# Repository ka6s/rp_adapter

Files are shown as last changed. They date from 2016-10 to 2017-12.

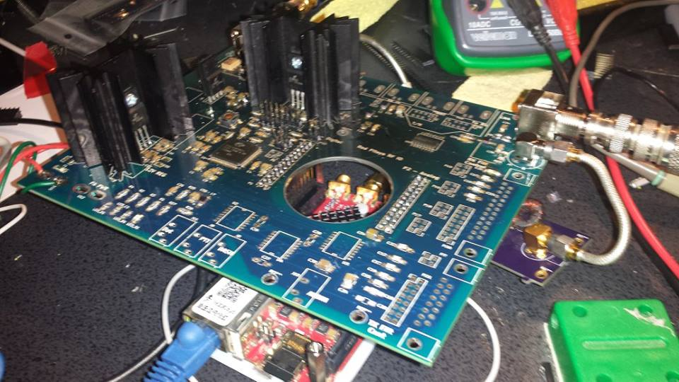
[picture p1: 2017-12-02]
DebugRev1.jpg

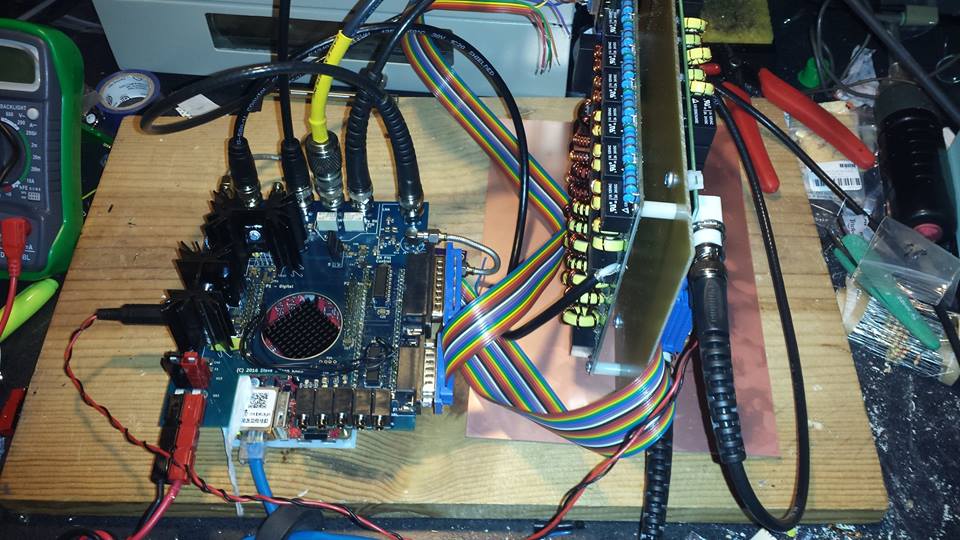
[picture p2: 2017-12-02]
rev3_with_filters.jpg

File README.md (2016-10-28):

# rp_adapter : v4

# rp_adapter

This is the layout of the 4th iteration of this board.  Currently the design in this directory is the 
transceiver consisting of a connector to the Red Pitaya, the OpenHPSDR TAPR LPU, the OpenHPSDR TAPR T/R board, 
a 1W PA taken from the OpenHPSDR Penelope board, and a simple 18db ish LNA.  

The connecitivy is built to interface to an external amplifier, the Hermes RX Filter from EB104.ru and
the 300W LPF from EB104.ru. You need to get the amp keying from the EB104.ru LPF board. 

Enjoy

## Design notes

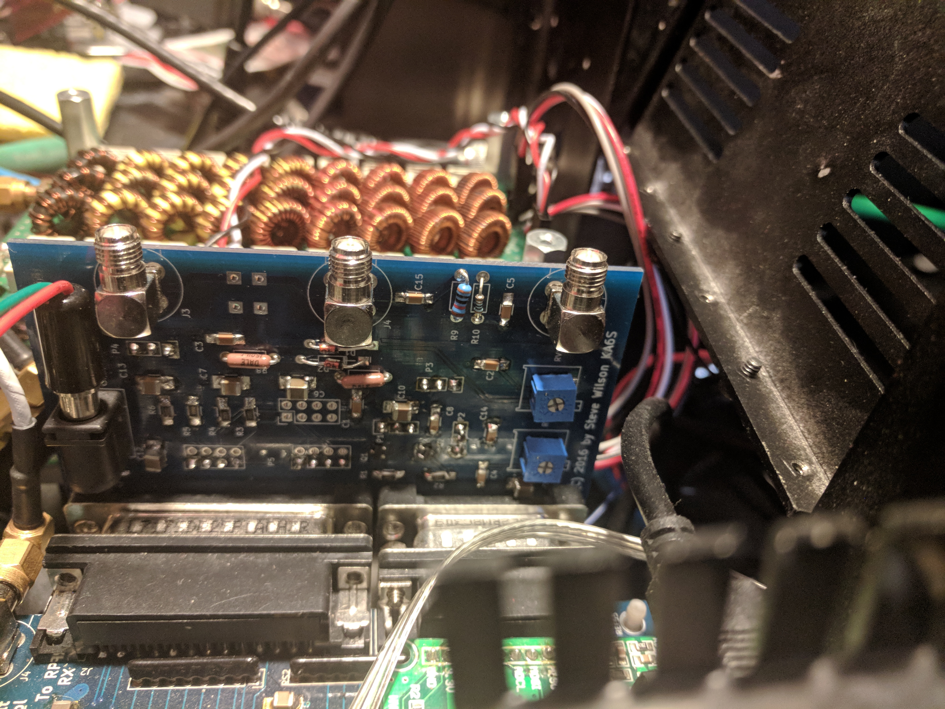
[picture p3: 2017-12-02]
swr.jpg

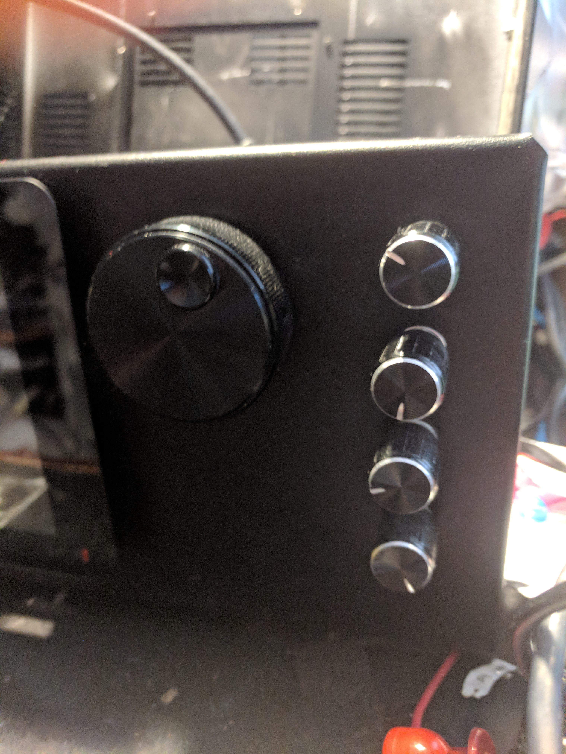
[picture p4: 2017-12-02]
knobs_front.jpg

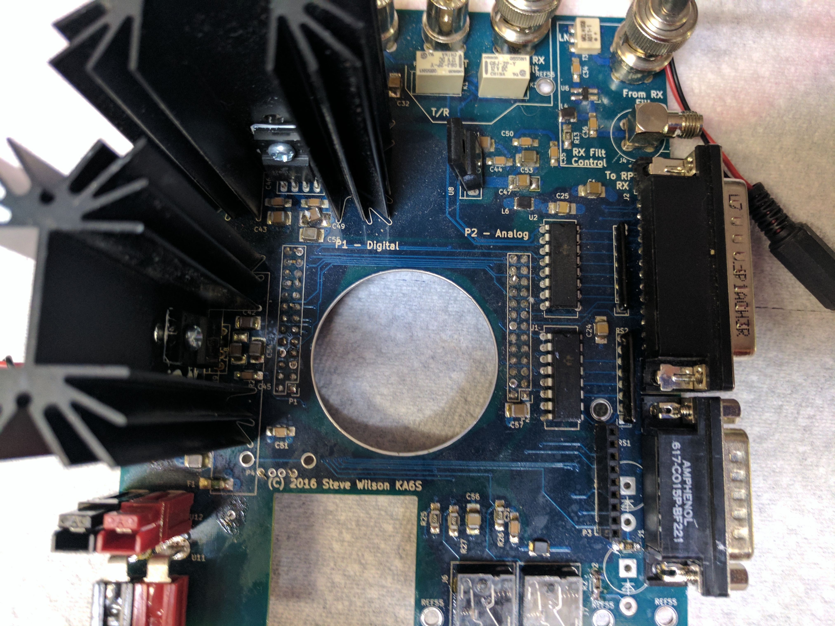
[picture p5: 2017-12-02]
ver4.jpg

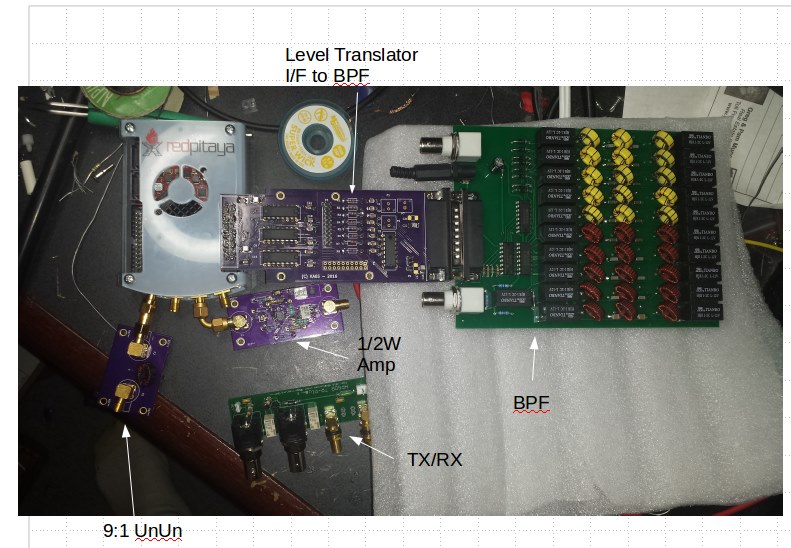
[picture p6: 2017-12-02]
Levelshifter.jpg

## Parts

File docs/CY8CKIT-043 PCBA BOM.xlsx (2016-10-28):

TITLE |  | CY8CKIT-043 PSoC 4 M-Series Prototyping Kit
PCA # |  | 121-60220-01 | REV 04
SCH # |  | 630-60252-01 | REV 04
DATE |  | 2015-06-24
Item | Qty | Reference | Value | Description | Manufacturer | Mfr Part Number | Sub Allowed | ROHS | UL Certified
1 | 1 | 600-60250-01 REV04 | - | PCB, 116.51 mm x 24.13 mm, High Tg, ENIG finish, 2 layer, Color = RED, Silk = WHITE | Cypress Semiconductor | 600-60250-01 | N/A | Yes | Yes
2 | 14 | C1,C4,C5,C6,C8,C11,C14,C18,C19,C20,C22,C29,C33,C34 | 0.1 uFd | CAP CER 0.1UF 10V 10% X5R 0402 | TDK Corporation | C1005X5R1A104K050BA | ASK | Yes | Yes
3 | 13 | C3,C15,C16,C17,C21,C23,C24,C25,C26,C27,C28,C31,C32 | 1.0 uFd | CAP CERAMIC 1.0UF 25V X5R 0603 10% | Taiyo Yuden | TMK107BJ105KA-T | ASK | Yes | Yes
4 | 1 | C9 | 18 pF | CAP CER 18PF 50V 1% NP0 0402 | Murata Electronics | GRM1555C1H180FA01D | ASK | Yes | Yes
5 | 1 | C10 | 2200 pFd | CAP CER 2200PF 50V 5% NP0 0805 | Murata | GRM2165C1H222JA01D | ASK | Yes | Yes
6 | 1 | C12 | 36 pF | CAP CER 36PF 50V 5% NP0 0402 | Murata Electronics | GRM1555C1H360JA01D | ASK | Yes | Yes
7 | 1 | C13 | 10000 pFd | CAP CER 10000PF 50V 5% NP0 0805 | Murata | GRM2195C1H103JA01D | ASK | Yes | Yes
8 | 1 | D1 | MBR0520L | DIODE SCHOTTKY 0.5A 20V SOD-123 | Fairchild Semiconductor | MBR0520L | ASK | Yes | Yes
9 | 1 | F1 | PTC Resettable Fuse | FUSE, PTC Resettable, 0.50A, 16V, 1210, SMD | Bel Fuse Inc | 0ZCH0050FF2G | ASK | Yes | Yes
10 | 1 | LED1 | User LED BLUE | LED, BLUE, CLEAR, 0805, SMD | Lite-On Inc | LTST-C170TBKT | ASK | Yes | Yes
11 | 1 | LED2 | Power LED Amber | LED 595NM AMB DIFF 0805 SMD | Avago Technologies | HSMA-C170 | ASK | Yes | Yes
12 | 1 | LED3 | Status LED Green | LED GREEN CLEAR 0805 SMD | Chicago Miniature | CMD17-21VGC/TR8 | ASK | Yes | Yes
13 | 3 | L1,L2,L3 | 330 OHM @ 100MHz | FILTER CHIP 330 OHM 1.5A 0603 | Murata Electronics | BLM18SG331TN1D | ASK | Yes | Yes
14 | 2 | R2,R3 | 15K | RES SMD 15K OHM 5% 1/10W 0402 | Panasonic - ECG | ERJ-2GEJ153X | ASK | Yes | Yes
15 | 2 | R4,R5 | 22E | RES SMD 22 OHM 1% 1/10W 0402 | Panasonic - ECG | ERJ-2RKF22R0X | ASK | Yes | Yes
16 | 2 | R6,R8 | 2.2K | RES 2.2K OHM 1/10W 5% 0603 SMD | Panasonic - ECG | ERJ-3GEYJ222V | ASK | Yes | Yes
17 | 2 | R7,R22 | ZERO | RES 0.0 OHM 1/8W 0805 SMD | Panasonic-ECG | ERJ-6GEY0R00V | ASK | Yes | Yes
18 | 1 | R9 | 560 ohm | RES 560 OHM 1/10W 5% 0603 SMD | Panasonic - ECG | ERJ-3GEYJ561V | ASK | Yes | Yes
19 | 2 | R10,R12 | 30K | RES SMD 30K OHM 5% 1/10W 0402 | Panasonic - ECG | ERJ-2GEJ303X | ASK | Yes | Yes
20 | 12 | R11,R13,R14,R16,R17,R18,R20,R21,R24,R26,R27,R28 | ZERO | RES 0.0 OHM 1/8W 0603 SMD | Panasonic-ECG | ERJ-3GEY0R00V | ASK | Yes | Yes
21 | 1 | R15 | 560 ohm | RES 560 OHM 1/8W 5% 0805 SMD | Panasonic - ECG | ERJ-6GEYJ561V | ASK | Yes | Yes
22 | 1 | R19 | 820 ohm | RES 820 OHM 1/8W 5% 0603 SMD | Panasonic - ECG | ERJ-3GEYJ821V | ASK | Yes | Yes
23 | 2 | SW1,SW3 | SW PUSHBUTTON | SWITCH TACTILE SPST-NO 0.05A 32V | C&K Components | KMR221GLFS | ASK | Yes | Yes
24 | 1 | U1 | PSoC 5LP | 68QFN PSoC 5LP chip for USB debug channel and USB-Serial interface | Cypress Semiconductor | CY8C5868LTI-LP039 | ASK | Yes | Yes
25 | 1 | U2 | PSoC 4200M | 68TQFP PSoC 4M | Cypress Semiconductor | CY8C4247AZI-M485 | ASK | Yes | Yes
26 | 1 | U3 | DUAL PMOS | MOSFET 2P-CH 20V 430MA SOT-563 | ON Semiconductor | NTZD3152PT1G | ASK | Yes | Yes
Label
27 | 1 | N/A | N/A | LBL, PCA Label, Vendor Code, Datecode, Serial Number 121-60220-01 Rev 04 (YYWWVVXXXXX) | Cypress Semiconductor |  | ASK | Yes | Yes
No load components
28 | 2 | C2,C30 | 0.1 uFd | CAP CER 0.1UF 10V 10% X5R 0402 | TDK Corporation | C1005X5R1A104K050BA | ASK | Yes | Yes
29 | 1 | C7 | 1.0 uFd | CAP CERAMIC 1.0UF 25V X5R 0603 10% | Taiyo Yuden | TMK107BJ105KA-T | ASK | Yes | Yes
30 | 1 | J4 | HDR 1x2 | CONN HEADR BRKWAY .100 02POS STR | TE Connectivity | 9-146280-0-02 | ASK | Yes | Yes
31 | 1 | J5 | 50MIL KEYED SMD | CONN HEADER 10 PIN 50MIL KEYED SMD | Samtec | FTSH-105-01-L-DV-K | ASK | Yes | Yes
32 | 1 | R1 | 4.7K | RES SMD 4.7K OHM 5% 1/10W 0402 | Panasonic - ECG | ERJ-2GEJ472X | ASK | Yes | Yes
33 | 1 | R25 | ZERO | RES 0.0 OHM 1/8W 0805 SMD | Panasonic - ECG | ERJ-6GEY0R00V | ASK | Yes | Yes
34 | 1 | R23 | 4.7K | RES 4.7K OHM 1/10W 5% 0603 SMD | Panasonic - ECG | ERJ-3GEYJ472V | ASK | Yes | Yes
35 | 1 | SW2 | SW PUSHBUTTON | SWITCH TACTILE SPST-NO 0.05A 32V | C&K Components | KMR221GLFS | ASK | Yes | Yes
36 | 1 | SW4 | DPDT SW | SWITCH SLIDE DPDT 200MA 12V | Copal Electronics | CL-SB-22B-02T | ASK | Yes | Yes
37 | 1 | TP5 | BLACK | TEST POINT 43 HOLE 65 PLATED BLACK | Keystone Electronics | 5001 | ASK | Yes | Yes
38 | 4 | TP1,TP2,TP3,TP4 | RED | TEST POINT 43 HOLE 65 PLATED RED | Keystone Electronics | 5000 | ASK | Yes | Yes
39 | 1 | U4 | EZ-BLE | EZ-BLE PRoC BLE Module, 10 mm X 10 mm X 1.8 mm | Cypress Semiconductor | CYBLE-022001-00 | ASK | Yes | Yes

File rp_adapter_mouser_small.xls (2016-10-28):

Mouser Part number | Manufacturer | Mfg Part Number | Description | Location | Quantity | Price 1 | Cost/Unit/10 | Location | Price 1 | Min\Mult Order Qty | Quoted Part Number
81-GRM422X105K50L (http://www.mouser.com/ProductDetail/Murata-Electronics/GRM32RR71H105KA01L/) | Murata | GRM32RR71H105KA01L (http://www.mouser.com/ProductDetail/Murata-Electronics/GRM32RR71H105KA01L/) | 1uF | C53,C55,C57,C54,C40 | 7 | 0.32 | 0.17 |  | $0.17 | 1\1 | 81-GRM422X105K50L
81-GRM422R106K16L (http://www.mouser.com/ProductDetail/Murata-Electronics/GRM32DR61C106KA01L/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) | Murata | GRM32DR61C106KA01L (http://www.mouser.com/ProductDetail/Murata-Electronics/GRM32DR61C106KA01L/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) | 10uF | C30,C2,C47,C49,C48,C41,C37,C42,C43 | 10 | 0.32 | 0.185 |  | $0.255 | 1\1 | 81-GRM422R106K16L
80-C1206C104K5R (http://www.mouser.com/ProductDetail/Kemet/C1206C104K5RACTU/) | Kemet | C1206C104K5RACTU (http://www.mouser.com/ProductDetail/Kemet/C1206C104K5RACTU/) | 0.1uF | C44,C50,C35,C36,C34,C33,C39,C38,C45,C51,C46,C52,C31 | 15 | 0.1 | 0.042 |  | $0.042 | 1\1 | 80-C1206C104K5R
80-C1210C107M4PACTU (http://www.mouser.com/ProductDetail/Kemet/C1210C107M4PACTU/) | Kemet | C1210C107M4PACTU (http://www.mouser.com/ProductDetail/Kemet/C1210C107M4PACTU/) | 100uF | C55,C54,C53,C40,C57,C1 | 7 | 2.46 | 0.836 |  | $2.46 | 1\1 | 80-C1210C107M4PACTU
490-PJ-002BH | Cui | PJ-002BH | BARREL_JACK | CON1 | 1 | 1.16 | 1.25 |  | $1.16 | 1\1 | 490-PJ-002BH
576-0437005.WR (http://www.mouser.com/ProductDetail/Littelfuse/0437005WR/) | Littelfuse (http://www.mouser.com/littelfuse) | 0437005.WR (http://www.mouser.com/ProductDetail/Littelfuse/0437005WR/) | FUSE | F1 | 1 | 0.92 | 0.688 |  | $0.92 | 1\1 | 576-0437005.WR
532-529801B25G | Aavid Thermalloy | 529801B02500G | HEATSINK | HS3,HS2 | 2 | 1.47 | 1.39 |  | $1.47 | 1\1 | 532-529801B25G
710-618015231221 (http://www.mouser.com/ProductDetail/Wurth-Electronics/618015231221/?qs=sGAEpiMZZMt93J8DTi5DC553G%252bzlR8Bc) | Wurth | 618015231221 (http://www.mouser.com/ProductDetail/Wurth-Electronics/618015231221/?qs=sGAEpiMZZMt93J8DTi5DC553G%252bzlR8Bc) | DB15 | J1 | 1 | 3.21 | 3.06 |  | $3.21 | 1\1 | 710-618015231221
523-L717SDB25P1ACH3R | Amphenol | L717SDB25P1ACH3R (http://www.mouser.com/ProductDetail/Amphenol-Commercial-Products/L717SDB25P1ACH3R/) | DB25 | J2 | 1 | 2.38 | 2.28 |  | $2.38 | 1\1 | 523-L717SDB25P1ACH3R
712-CONSMA002 (http://www.mouser.com/ProductDetail/Linx-Technologies/CONSMA002/?qs=K5ta8V%252bWhtYroTuiMsq2AA%3D%3D) | Linx Tech | CONSMA002 (http://www.mouser.com/ProductDetail/Linx-Technologies/CONSMA002/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) | SMA | J4,J3,J5 | 3 | 3.31 | 3.03 |  | $3.31 | 1\1 | 712-CONSMA002
490-SJ1-3533N (http://www.mouser.com/ProductDetail/CUI/SJ1-3533N/) | Cui | SJ1-3533N | JACK_2P | J11,J10,J9,J8,J6 | 5 | 1.6 | 1.24 |  | $1.60 | 1\1 | 490-SJ1-3533N
653-G6J-2P-Y-DC12 (http://www.mouser.com/ProductDetail/Omron-Electronics/G6J-2P-Y-DC12/) | Omron | G6J-2P-Y-DC12 | RELAY_RF | K2,K1 | 2 | 4.29 | 4.03 |  | $4.29 | 1\1 | 653-G6J-2P-Y-DC12
81-NFZ32BW621HN10L | Murata | NFZ32BW621HN10L | FB | L5,L4,L6,L3,L7 | 6 | 0.41 | 0.269 |  | $0.269 | 1\1 | 81-NFZ32BW621HN10L
563-BC-32678 | Bud Industries | BC-32678 | CONN_02X13 | P2,P1 | 2 | 2 | 1.8 |  | $2.00 | 1\1 | 563-BC-32678
652-CR1206FX-75R0ELF (http://www.mouser.com/ProductDetail/Bourns/CR1206-FX-75R0ELF/) | Bourns | CR1206-FX-75R0ELF (http://www.mouser.com/ProductDetail/Bourns/CR1206-FX-75R0ELF/) | 75 | R13 | 5 | 0.1 | 0.042 |  | $0.10 | 1\1 | 652-CR1206FX-75R0ELF
667-ERJ-8RQF5R1V (http://www.mouser.com/ProductDetail/Panasonic/ERJ-8RQF5R1V/) | Panasonic | ERJ-8RQF5R1V (http://www.mouser.com/ProductDetail/Panasonic/ERJ-8RQF5R1V/) | 5R1 | R22,R21 | 5 | 0.56 | 0.22 |  | $0.56 | 1\1 | 667-ERJ-8RQF5R1V
71-CP00102R200JE663 | Vishay | CP00102R200JE663 | 2R2 | R24,R23 | 2 | 0.67 | 0.495 |  | $4.29 | 1\1 | 653-G6J-2P-Y-DC12
667-ERJ-8GEYJ472V (http://www.mouser.com/ProductDetail/Panasonic/ERJ-8GEYJ472V/) | Panasonic | ERJ-8GEYJ472V (http://www.mouser.com/ProductDetail/Panasonic/ERJ-8GEYJ472V/) | 4.7K | R27,R25,R26 | 5 | 0.1 |  |  | $0.022 | 1\1 | 667-ERJ-8GEYJ472V
512-KA278R12CTU (http://www.mouser.com/ProductDetail/Fairchild-Semiconductor/KA278R12CTU/) | Fairchild | KA278R12CTU (http://www.mouser.com/ProductDetail/Fairchild-Semiconductor/KA278R12CTU/) | KA278R12 | U10 | 1 | 0.99 | 0.848 |  | $0.99 | 1\1 | 512-KA278R12CTU
879-1336G1 (http://www.mouser.com/ProductDetail/Anderson-Power-Products/1336G1/?qs=sGAEpiMZZMuP%2FQeRSdvksJ%2FdnJShAKpx) | Anderson Power Products (http://www.mouser.com/Anderson-Power-Products/) | 1336G1 (http://www.mouser.com/ProductDetail/Anderson-Power-Products/1336G1/?qs=sGAEpiMZZMuP%2FQeRSdvksJ%2FdnJShAKpx) | PwrPole | U11 | 2 | 0.54 |  |  | $0.54 | 1\1 | 879-1336G1
879-1327G6 (http://www.mouser.com/ProductDetail/Anderson-Power-Products/1327G6/?qs=sGAEpiMZZMuP%2FQeRSdvksFwvD3ebCz4Y) | Anderson Power Products (http://www.mouser.com/Anderson-Power-Products/) | 1327G6 | 1327G6 (http://www.mouser.com/ProductDetail/Anderson-Power-Products/1327G6/?qs=sGAEpiMZZMuP%2FQeRSdvksFwvD3ebCz4Y) | U12,U11 | 2 |  |  |  | $0.48 | 1\1 | 879-1327G6
879-1327 (http://www.mouser.com/ProductDetail/Anderson-Power-Products/1327/?qs=sGAEpiMZZMuP%2FQeRSdvksHAvir4742Xo) | Anderson Power Products (http://www.mouser.com/Anderson-Power-Products/) | 1327 | PwrPole Shroud Red | U12,U11 | 2 |  |  |  | $0.50 | 1\1 | 879-1327
879-1335G1 (http://www.mouser.com/ProductDetail/Anderson-Power-Products/1335G1/?qs=sGAEpiMZZMuP%2FQeRSdvksBiQHnjEfqU3) | Anderson Power Products (http://www.mouser.com/Anderson-Power-Products/) | 1335G1 (http://www.mouser.com/ProductDetail/Anderson-Power-Products/1335G1/?qs=sGAEpiMZZMuP%2FQeRSdvksBiQHnjEfqU3) | Powe Pole Vert | U12 | 2 |  |  |  |  | 1\1 | 879-1335G1
700-MAX2611EUS+T (http://www.mouser.com/ProductDetail/Maxim-Integrated/MAX2611EUS+T/?qs=GxOUx7aO6nzhsdyrBwYTYA%3D%3D) | Maxim | MAX2611EUS+T | MAX2611 | U6 | 1 | 1.78 | 1.68 |  | $1.78 | 1\1 | 700-MAX2611EUS+T
595-OPA2674ID (http://www.mouser.com/ProductDetail/Texas-Instruments/OPA2674ID/?qs=7nS3%252bbEUL6ta%252bQbwv%2FJuYg%3D%3D) | TI | OPA2674ID (http://www.mouser.com/ProductDetail/Texas-Instruments/OPA2674ID/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) | OPA26741C | U7 | 1 | 4.14 | 3.72 |  | $4.14 | 1\1 | 595-OPA2674ID
512-KA278R05CTU | Fairchild | KA278R05CTU | KA278R05 | U8,U9 | 2 | 0.98 | 0.836 |  | $0.98 | 1\1 | 512-KA278R05CTU
571-5-1634506-1 | TE Connectivity (http://www.mouser.com/TE-Connectivity/) | 5-1634506-1 | BNC_VERTICAL | P8,P10,P14,P9,P15 | 5 | 1.36
511-ULN2001A | STMicro | ULN2001A | ULN2004A | U1,U2 | 2 | 0.47
279-CBT50J100R (http://www.mouser.com/ProductDetail/TE-Connectivity-Neohm/CBT50J100R/) | TE Connectivity | CBT25J100R (http://www.mouser.com/ProductDetail/TE-Connectivity-Neohm/CBT25J100R/) | 100 | R15,R16 | 2
603-MFR-25FRF521K (http://www.mouser.com/ProductDetail/Yageo/MFR-25FRF52-1K/) | Yageo | MFR-25FRF52-1K (http://www.mouser.com/ProductDetail/Yageo/MFR-25FRF52-1K/) | 1K | R18,R17,R19,R20 | 4
 |  |  | CONN_01X29 | P3,P4 | 2

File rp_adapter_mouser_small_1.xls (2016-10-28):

Mouser Part number | Manufacturer | Mfg Part Number | Description | Location | Quantity | Price 1 | Cost/Unit/10 | Location | Price 1 | Min\Mult Order Qty | Quoted Part Number
81-GRM422X105K50L (http://www.mouser.com/ProductDetail/Murata-Electronics/GRM32RR71H105KA01L/) | Murata | GRM32RR71H105KA01L (http://www.mouser.com/ProductDetail/Murata-Electronics/GRM32RR71H105KA01L/) | 1uF | C56,C32,C25,C24,C9,C7,C5,C3,C2,C1 | 20 | 0.32 | 0.17 |  | $0.17 | 1\1 | 81-GRM422X105K50L
80-C1206C101K5R (http://www.mouser.com/ProductDetail/Kemet/C1206C101K5RACTU/) | Kemet | C1206C101K5RACTU (http://www.mouser.com/ProductDetail/Kemet/C1206C101K5RACTU/) | 100pF | C23,C22,C21,C20,C18,C17,C16,C15,C14,C13,C12,C19 | 15 | 0.1 | 0.042 |  | $0.185 | 1\1 | 80-C1206C101K5R
81-GRM422R106K16L (http://www.mouser.com/ProductDetail/Murata-Electronics/GRM32DR61C106KA01L/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) | Murata | GRM32DR61C106KA01L (http://www.mouser.com/ProductDetail/Murata-Electronics/GRM32DR61C106KA01L/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) | 10uF | C49,C48,C47,C43,C42,C41,C37,C30 | 10 | 0.32 | 0.185 |  | $0.255 | 1\1 | 81-GRM422R106K16L
80-C1206C104K5R (http://www.mouser.com/ProductDetail/Kemet/C1206C104K5RACTU/) | Kemet | C1206C104K5RACTU (http://www.mouser.com/ProductDetail/Kemet/C1206C104K5RACTU/) | 0.1uF | C52,C51,C50,C46,C45,C44,C39,C38,C36,C35,C34,C33,C31,C29,C28,C27,C26,C11,C10,C8,C6,C4 | 25 | 0.1 | 0.042 |  | $0.042 | 1\1 | 80-C1206C104K5R
80-C1210C107M4PACTU (http://www.mouser.com/ProductDetail/Kemet/C1210C107M4PACTU/) | Kemet | C1210C107M4PACTU (http://www.mouser.com/ProductDetail/Kemet/C1210C107M4PACTU/) | 100uF | C55,C54,C53,C40,C57 (1210) | 8 | 2.46 | 0.836 |  | $2.46 | 1\1 | 80-C1210C107M4PACTU
490-PJ-002BH | Cui | PJ-002BH | BARREL_JACK | CON1 | 1 | 1.16 | 1.25 |  | $1.16 | 1\1 | 490-PJ-002BH
576-0437005.WR (http://www.mouser.com/ProductDetail/Littelfuse/0437005WR/) | Littelfuse (http://www.mouser.com/littelfuse) | 0437005.WR (http://www.mouser.com/ProductDetail/Littelfuse/0437005WR/) | FUSE | F1 | 1 | 0.92 | 0.688 |  | $0.92 | 1\1 | 576-0437005.WR
532-529801B25G | Aavid Thermalloy | 529801B02500G | HEATSINK | HS3,HS2 | 2 | 1.47 | 1.39 |  | $1.47 | 1\1 | 532-529801B25G
710-618015231221 (http://www.mouser.com/ProductDetail/Wurth-Electronics/618015231221/?qs=sGAEpiMZZMt93J8DTi5DC553G%252bzlR8Bc) | Wurth | 618015231221 (http://www.mouser.com/ProductDetail/Wurth-Electronics/618015231221/?qs=sGAEpiMZZMt93J8DTi5DC553G%252bzlR8Bc) | DB15 | J1 | 1 | 3.21 | 3.06 |  | $3.21 | 1\1 | 710-618015231221
523-L717SDB25P1ACH3R | Amphenol | L717SDB25P1ACH3R (http://www.mouser.com/ProductDetail/Amphenol-Commercial-Products/L717SDB25P1ACH3R/) | DB25 | J2 | 1 | 2.38 | 2.28 |  | $2.38 | 1\1 | 523-L717SDB25P1ACH3R
712-CONSMA002 (http://www.mouser.com/ProductDetail/Linx-Technologies/CONSMA002/?qs=K5ta8V%252bWhtYroTuiMsq2AA%3D%3D) | Linx Tech | CONSMA002 (http://www.mouser.com/ProductDetail/Linx-Technologies/CONSMA002/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) | SMA | J5,J4,J3 | 3 | 3.31 | 3.03 |  | $3.31 | 1\1 | 712-CONSMA002
490-SJ1-3533N (http://www.mouser.com/ProductDetail/CUI/SJ1-3533N/) | Cui | SJ1-3533N | JACK_2P | J11,J10,J9,J8,J6 | 5 | 1.6 | 1.24 |  | $1.60 | 1\1 | 490-SJ1-3533N
653-G6J-2P-Y-DC12 (http://www.mouser.com/ProductDetail/Omron-Electronics/G6J-2P-Y-DC12/) | Omron | G6J-2P-Y-DC12 | RELAY_RF | K2,K1 | 2 | 4.29 | 4.03 |  | $4.29 | 1\1 | 653-G6J-2P-Y-DC12
81-LQH31MNR47K03L (http://www.mouser.com/ProductDetail/Murata-Electronics/LQH31MNR47K03L/) | Murata | LQH31MNR47K03L (http://www.mouser.com/ProductDetail/Murata-Electronics/LQH31MNR47K03L/) | 0.47uH | L2,L1 | 2 | 0.44 | 0.335 |  | $0.44 | 1\1 | 81-LQM31PNR47MC0L
81-NFZ32BW621HN10L | Murata | NFZ32BW621HN10L | FB | L6,L5,L4,L3,L7 | 6 | 0.41 | 0.269 |  | $0.269 | 1\1 | 81-NFZ32BW621HN10L
645-598-8270-107F (http://www.mouser.com/ProductDetail/Dialight/598-8270-107F/) | Dialight | 598-8270-107F (http://www.mouser.com/ProductDetail/Dialight/598-8270-107F/) | LED | LED_D1,LED_C1,LED_B1,LED_A1 | 4 | 0.46 |  |  | $0.46 | 1\1 | 645-598-8270-107F
563-BC-32678 | Bud Industries | BC-32678 | CONN_02X13 | P2,P1 | 2 | 2 | 1.8 |  | $2.00 | 1\1 | 563-BC-32678
571-5227677-1 | TE Connectivity | 5227677-1 | BNC | P15,P14,P11,P10,P9,P8 | 6 | 3.3 | 3.17 |  | $3.30 | 1\1 | 571-5227677-1
652-CR1206FX-75R0ELF (http://www.mouser.com/ProductDetail/Bourns/CR1206-FX-75R0ELF/) | Bourns | CR1206-FX-75R0ELF (http://www.mouser.com/ProductDetail/Bourns/CR1206-FX-75R0ELF/) | 75 | R13 | 5 | 0.1 | 0.042 |  | $0.10 | 1\1 | 652-CR1206FX-75R0ELF
667-ERJ-8GEYJ101V (http://www.mouser.com/ProductDetail/Panasonic/ERJ-8GEYJ101V/) | Bourns | ERJ-8GEYJ101V (http://www.mouser.com/ProductDetail/Panasonic/ERJ-8GEYJ101V/) | 100 | R16,R15 | 5 | 0.1 | 0.022 |  | $0.10 | 1\1 | 667-ERJ-8GEYJ101V
652-CR1206-JW-102ELF (http://www.mouser.com/ProductDetail/Bourns/CR1206-JW-102ELF/) | Bourns | CR1206-JW-102ELF (http://www.mouser.com/ProductDetail/Bourns/CR1206-JW-102ELF/) | 1K | R20,R19,R18,R17 | 5 | 0.1 | 0.039 |  | $0.038 | 1\1 | 652-CR1206-JW-102ELF
667-ERJ-8RQF5R1V (http://www.mouser.com/ProductDetail/Panasonic/ERJ-8RQF5R1V/) | Panasonic | ERJ-8RQF5R1V (http://www.mouser.com/ProductDetail/Panasonic/ERJ-8RQF5R1V/) | 5R1 | R22,R21 | 5 | 0.56 | 0.22 |  | $0.56 | 1\1 | 667-ERJ-8RQF5R1V
71-CP00102R200JE663 | Vishay | CP00102R200JE663 | 2R2 | R24,R23 | 2 | 0.67 | 0.495 |  | $4.29 | 1\1 | 653-G6J-2P-Y-DC12
667-ERJ-8GEYJ472V (http://www.mouser.com/ProductDetail/Panasonic/ERJ-8GEYJ472V/) | Panasonic | ERJ-8GEYJ472V (http://www.mouser.com/ProductDetail/Panasonic/ERJ-8GEYJ472V/) | 4.7K | R26,R25,R5,R4,R3,R2,R1,R27 | 10 | 0.1 |  |  | $0.022 | 1\1 | 667-ERJ-8GEYJ472V
791-WR12X000PTL | Waisun | WR12X000 PTL | 0 | R12,R11,R10,R9,R8,R7,R6 | 10 | 0.11 |  |  | $0.11 | 1\1 | 791-WR12X000PTL
653-B3S-1000 (http://www.mouser.com/ProductDetail/Omron-Electronics/B3S-1000/) | Omron | B3S-1000 (http://www.mouser.com/ProductDetail/Omron-Electronics/B3S-1000/) | SW_PUSH | SW1 | 1 | 0.61 |  |  | $0.61 | 1\1 | 653-B3S-1000
727-CY8C4247AXI-M485 (http://www.mouser.com/ProductDetail/Cypress-Semiconductor/CY8C4247AXI-M485/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) | Cypress | CY8C4247AXI-M485 | CY8C4247AXIM | U1 | 1 | 6.37 | 5.51 |  | $6.37 | 1\1 | 727-CY8C4247AXI-M485
512-KA278R12CTU (http://www.mouser.com/ProductDetail/Fairchild-Semiconductor/KA278R12CTU/) | Fairchild | KA278R12CTU (http://www.mouser.com/ProductDetail/Fairchild-Semiconductor/KA278R12CTU/) | KA278R12 | U10 | 1 | 0.99 | 0.848 |  | $0.99 | 1\1 | 512-KA278R12CTU
879-1336G1 (http://www.mouser.com/ProductDetail/Anderson-Power-Products/1336G1/?qs=sGAEpiMZZMuP%2FQeRSdvksJ%2FdnJShAKpx) | Anderson Power Products (http://www.mouser.com/Anderson-Power-Products/) | 1336G1 (http://www.mouser.com/ProductDetail/Anderson-Power-Products/1336G1/?qs=sGAEpiMZZMuP%2FQeRSdvksJ%2FdnJShAKpx) | PwrPole | U11 | 2 | 0.54 |  |  | $0.54 | 1\1 | 879-1336G1
879-1327G6 (http://www.mouser.com/ProductDetail/Anderson-Power-Products/1327G6/?qs=sGAEpiMZZMuP%2FQeRSdvksFwvD3ebCz4Y) | Anderson Power Products (http://www.mouser.com/Anderson-Power-Products/) | 1327G6 | 1327G6 (http://www.mouser.com/ProductDetail/Anderson-Power-Products/1327G6/?qs=sGAEpiMZZMuP%2FQeRSdvksFwvD3ebCz4Y) | U12,U11 | 2 |  |  |  | $0.48 | 1\1 | 879-1327G6
879-1327 (http://www.mouser.com/ProductDetail/Anderson-Power-Products/1327/?qs=sGAEpiMZZMuP%2FQeRSdvksHAvir4742Xo) | Anderson Power Products (http://www.mouser.com/Anderson-Power-Products/) | 1327 | PwrPole Shroud Red | U12,U11 | 2 |  |  |  | $0.50 | 1\1 | 879-1327
879-1335G1 (http://www.mouser.com/ProductDetail/Anderson-Power-Products/1335G1/?qs=sGAEpiMZZMuP%2FQeRSdvksBiQHnjEfqU3) | Anderson Power Products (http://www.mouser.com/Anderson-Power-Products/) | 1335G1 (http://www.mouser.com/ProductDetail/Anderson-Power-Products/1335G1/?qs=sGAEpiMZZMuP%2FQeRSdvksBiQHnjEfqU3) | Powe Pole Vert | U12 | 2 |  |  |  |  | 1\1 | 879-1335G1
595-CD4504BPWR (http://www.mouser.com/ProductDetail/Texas-Instruments/CD4504BPWR/?qs=LSR%252bNeaw%2FwDSi1l0SFbsAw%3D%3D) | TI | CD4504BPWR (http://www.mouser.com/ProductDetail/Texas-Instruments/CD4504BPWR/?qs=sGAEpiMZZMt7FrWooXVB1wQa44IR8MfB) | 4504 | U2,U3,U4 | 3 | 0.44 | 0.368 |  | $0.44 | 1\1 | 595-CD4504BPWR
595-ULN2003ADR | ULN2003ADR (http://www.mouser.com/ProductDetail/Texas-Instruments/ULN2003ADR/?qs=D5pVkbrsqqI8WxXD0eSvDA%3D%3D) | ULN2003ADR (http://www.mouser.com/ProductDetail/Texas-Instruments/ULN2003ADR/?qs=sGAEpiMZZMtYFXwiBRPs04XApsoE6l9l) | ULN2003 | U5 | 1 | 0.52 | 0.433 |  | $0.52 | 1\1 | 595-ULN2003ADR
700-MAX2611EUS+T (http://www.mouser.com/ProductDetail/Maxim-Integrated/MAX2611EUS+T/?qs=GxOUx7aO6nzhsdyrBwYTYA%3D%3D) | Maxim | MAX2611EUS+T | MAX2611 | U6 | 1 | 1.78 | 1.68 |  | $1.78 | 1\1 | 700-MAX2611EUS+T
595-OPA2674ID (http://www.mouser.com/ProductDetail/Texas-Instruments/OPA2674ID/?qs=7nS3%252bbEUL6ta%252bQbwv%2FJuYg%3D%3D) | TI | OPA2674ID (http://www.mouser.com/ProductDetail/Texas-Instruments/OPA2674ID/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) | OPA26741C | U7 | 1 | 4.14 | 3.72 |  | $4.14 | 1\1 | 595-OPA2674ID
512-KA278R05CTU | Fairchild | KA278R05CTU | KA278R05 | U9,U8 | 2 | 0.98 | 0.836 |  | $0.98 | 1\1 | 512-KA278R05CTU

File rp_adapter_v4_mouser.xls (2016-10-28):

Id | Mouser Part number | Designation | Designator | Package | Quantity | Designation | Supplier and ref
1 | 652-CR1206FX-75R0ELF (http://www.mouser.com/ProductDetail/Bourns/CR1206-FX-75R0ELF/) | 75 | R13 | R_1206_HandSoldering | 1 | 75
2 | 279-CBT50J100R (http://www.mouser.com/ProductDetail/TE-Connectivity-Neohm/CBT50J100R/) | 100 | R15,R16 | Resistor_Horizontal_RM7mm | 4 | 100
3 | 80-C1206C104K5R (http://www.mouser.com/ProductDetail/Kemet/C1206C104K5RACTU/) | 0.1uF | C51,C44,C50,C35,C36,C34,C33,C39,C38,C45,C46,C52,C31 | C_1206_HandSoldering | 20 | 0.1uF
4 | 80-C1210C107M4PACTU (http://www.mouser.com/ProductDetail/Kemet/C1210C107M4PACTU/) | 100uF | C1, C53,C55,C57,C54,C40,C11 | SMD-1210_Pol | 10 | 100uF
6 | 81-GRM422R106K16L (http://www.mouser.com/ProductDetail/Murata-Electronics/GRM32DR61C106KA01L/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) | 10uF | C41,C37,C42,C43,C47,C49,C48 | SMD-1210_Pol | 10 | 10uF
8 | 603-MFR-25FRF521K (http://www.mouser.com/ProductDetail/Yageo/MFR-25FRF52-1K/) | 1K | R18,R17,R19,R20 | Resistor_Horizontal_RM7mm | 10 | 1K
9 | 755-ESR18EZPJ102 (http://www.mouser.com/ProductDetail/ROHM-Semiconductor/ESR18EZPJ102/?qs=sGAEpiMZZMuuBt6TL7D%2F6AtTj0am7JFA) | 1K | R1,R2 | R_1206_HandSoldering | 5 | 1K
11 | 81-GRM422X105K50L (http://www.mouser.com/ProductDetail/Murata-Electronics/GRM32RR71H105KA01L/) | 1uF | C56,C32,C24,C25 | C_1210_HandSoldering | 6 | 1uF
12 | 71-CP00102R200JE663 | 2R2 | R23,R24 | RES_10W | 2 | 2R2
13 | 667-ERJ-8GEYJ472V (http://www.mouser.com/ProductDetail/Panasonic/ERJ-8GEYJ472V/) | 4.7K | R27,R25,R26 | R_1206_HandSoldering | 5 | 4.7K
14 | 660-MF1/4DCT52R4R99F (http://www.mouser.com/ProductDetail/KOA-Speer/MF1-4DCT52R4R99F/) | 4R99 | R21,R22 | Resistor_Horizontal_RM7mm | 5 | 4R99
17 | 490-PJ-002BH | BARREL_JACK | CON1 | BARREL_JACK | 1 | BARREL_JACK
18 | 571-5-1634506-1 | BNC | P8,P10,P14,P9,P15 | BNC_VERTICAL | 5 | BNC
21 | 563-BC-32678 | CONN_02X13 | P2,P1 | Pin_Header_Straight_2x13 | 2 | CONN_02X13
22 | 710-618015231221 (http://www.mouser.com/ProductDetail/Wurth-Electronics/618015231221/?qs=sGAEpiMZZMt93J8DTi5DC553G%252bzlR8Bc) | DB15 | J1 | DB15FC | 1 | DB15
23 | 523-L717SDB25P1ACH3R | DB25 | J2 | DB25FC | 1 | DB25
24 | 81-NFZ32BW621HN10L | FB | L3,L4,L5,L6,L7 | FB | 7 | FB
25 | 576-0437005.WR (http://www.mouser.com/ProductDetail/Littelfuse/0437005WR/) | FUSE | F1 | Fuse_SMD1206_HandSoldering | 2 | FUSE
26 | 588-FA-T220-64E | HEATSINK | HS3,HS2 | Heatsink_Fischer_SK129-STS_42x25mm_2xDrill2.5mm | 2 | HEATSINK
27 | 490-SJ1-3513 (http://www.mouser.com/ProductDetail/CUI/SJ1-3513/?qs=sGAEpiMZZMs8jstQXqv0yXq059P3rkIHcE6LecbulTY%3D) | JACK_3P | J6,J7 | JACK_3P | 3 | JACK_3P
28 | 512-KA278R05CTU | KA278R05 | U8,U9 | TO-220_4pin_vertical | 2 | KA278R05
29 | 512-KA278R12CTU (http://www.mouser.com/ProductDetail/Fairchild-Semiconductor/KA278R12CTU/) | KA278R12 | U10 | TO-220_4pin_vertical | 1 | KA278R12
30 | 700-MAX2611EUS+T (http://www.mouser.com/ProductDetail/Maxim-Integrated/MAX2611EUS+T/?qs=GxOUx7aO6nzhsdyrBwYTYA%3D%3D) | MAX2611 | U6 | SOT-143_Handsoldering | 2 | MAX2611
31 | 595-OPA2674ID (http://www.mouser.com/ProductDetail/Texas-Instruments/OPA2674ID/?qs=7nS3%252bbEUL6ta%252bQbwv%2FJuYg%3D%3D) | OPA26741C | U7 | SOIC-8-N | 1 | OPA26741C
32 | 879-1335G1 (http://www.mouser.com/ProductDetail/Anderson-Power-Products/1335G1/?qs=sGAEpiMZZMuP%2FQeRSdvksBiQHnjEfqU3) | PwrPole | U11,U12 | Power Pole vert | 2 | PwrPole
 | 879-1336G1 (http://www.mouser.com/ProductDetail/Anderson-Power-Products/1336G1/?qs=sGAEpiMZZMuP%2FQeRSdvksJ%2FdnJShAKpx) | PwrPole |  | RA_POWER_POLE | 2
 | 879-1327 (http://www.mouser.com/ProductDetail/Anderson-Power-Products/1327/?qs=sGAEpiMZZMuP%2FQeRSdvksHAvir4742Xo) | PwrPole |  | Power Poll shroud | 4
33 | 653-G6J-2P-Y-DC12 (http://www.mouser.com/ProductDetail/Omron-Electronics/G6J-2P-Y-DC12/) | RELAY_RF | K1,K2 | RF_RELAY | 2 | RELAY_RF
34 | 858-L081S102LF (https://www.mouser.com/Search/ProductDetail.aspx) | RSIP7 | RS1,RS2 | Pin_Header_Straight_1x08 | 2 | RSIP7
35 | 712-CONSMA002 (http://www.mouser.com/ProductDetail/Linx-Technologies/CONSMA002/?qs=K5ta8V%252bWhtYroTuiMsq2AA%3D%3D) | SMA | J4,J3,J5 | SMA_F_RA | 3 | SMA
37 | 595-ULN2003AN (https://www.mouser.com/Search/ProductDetail.aspx) | ULN2003A | U1,U2 | DIP-16_W7.62mm | 2 | ULN2004A
38 | 595-ULN2003AN (https://www.mouser.com/Search/ProductDetail.aspx) | USB_A | P4 | USBA_VERT_STVW | 1 | USB_A
39 | 863-1N5913BRLG (http://www.mouser.com/ProductDetail/ON-Semiconductor/1N5913BRLG/) | ZENER | D1,D2 | Diode_P600_Vertical_AnodeUp | 2 | ZENER

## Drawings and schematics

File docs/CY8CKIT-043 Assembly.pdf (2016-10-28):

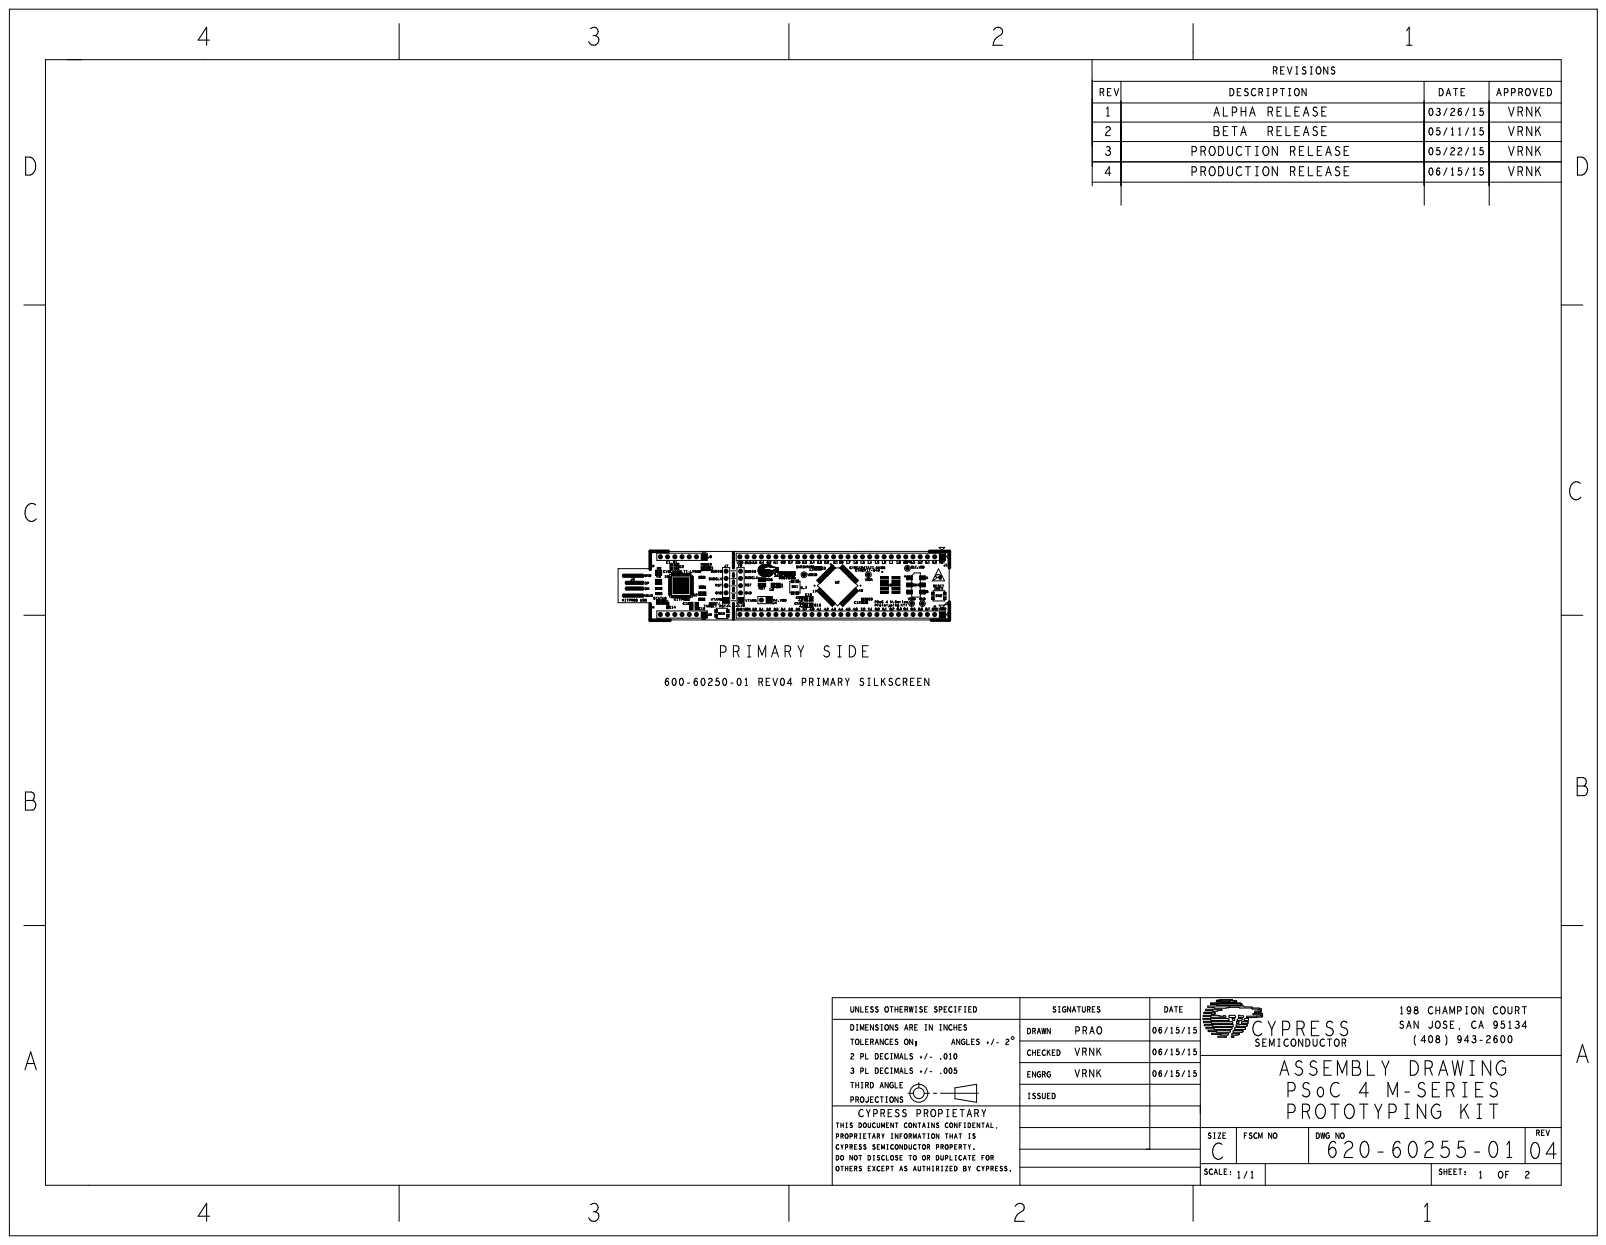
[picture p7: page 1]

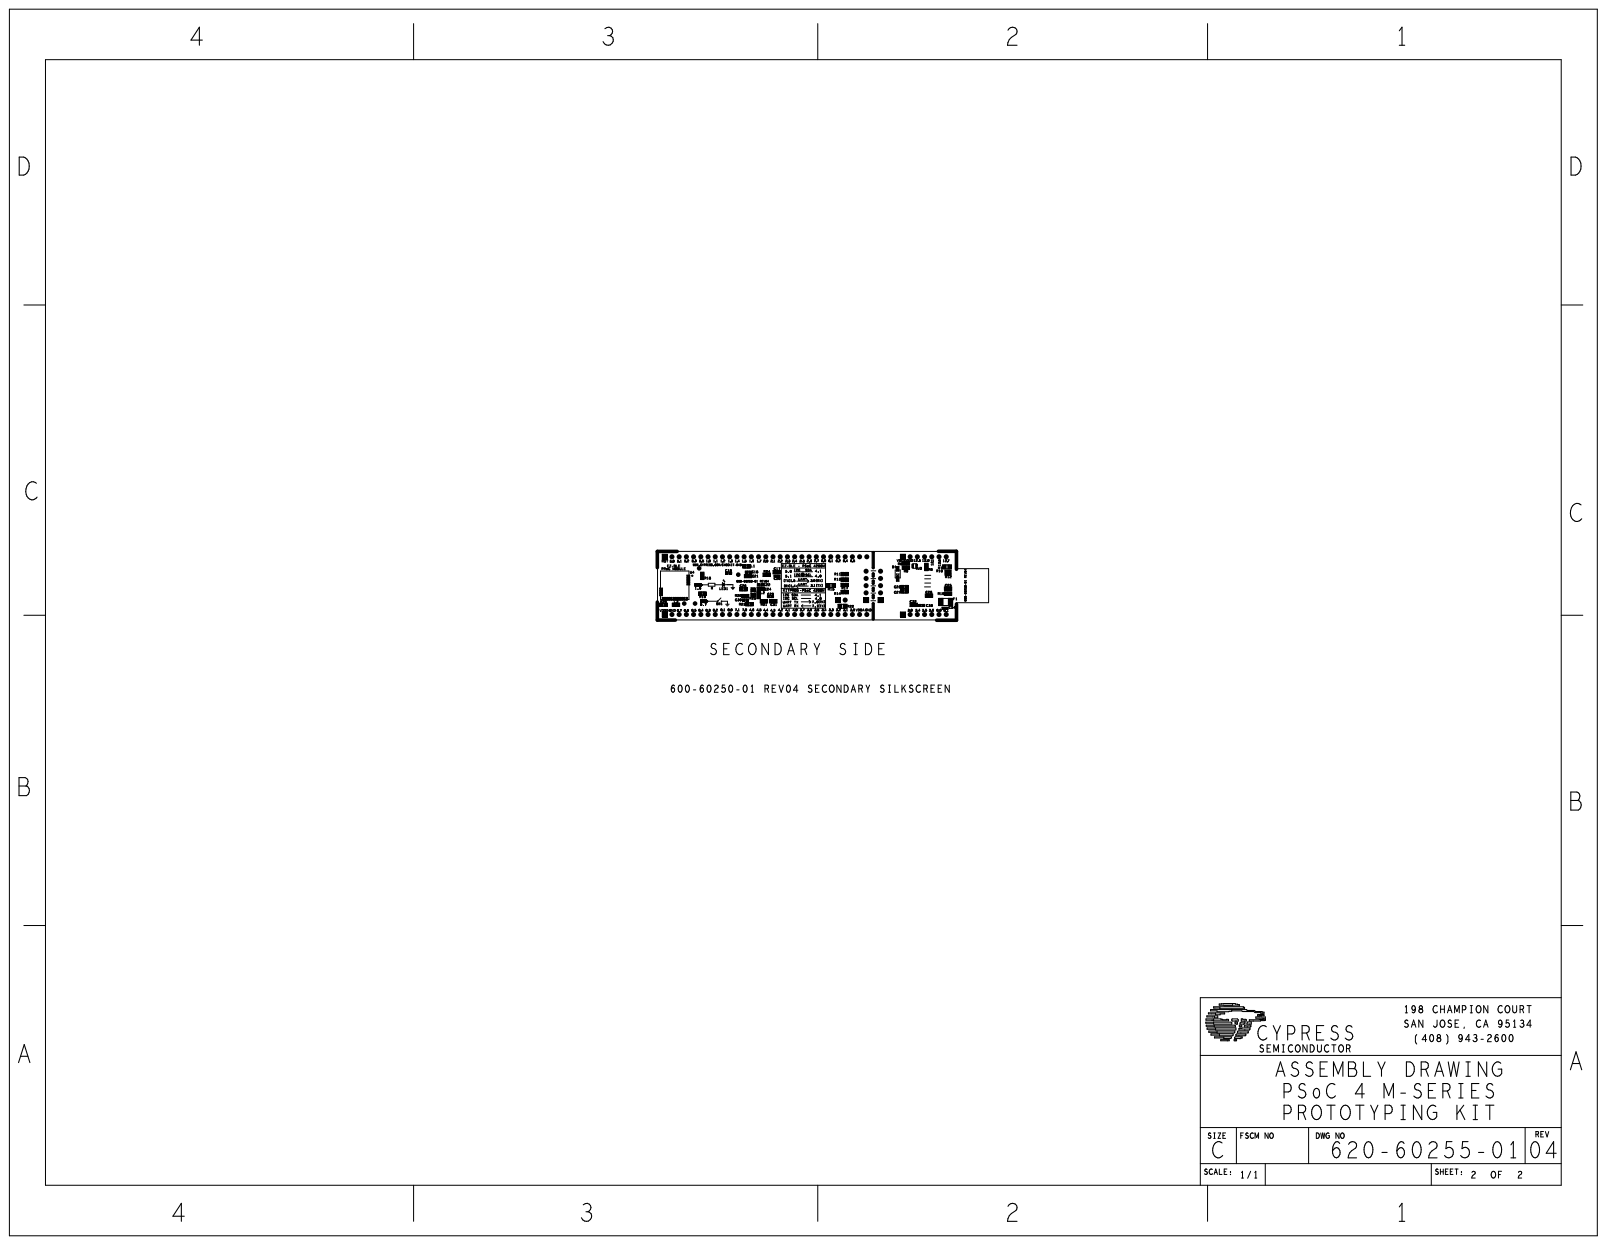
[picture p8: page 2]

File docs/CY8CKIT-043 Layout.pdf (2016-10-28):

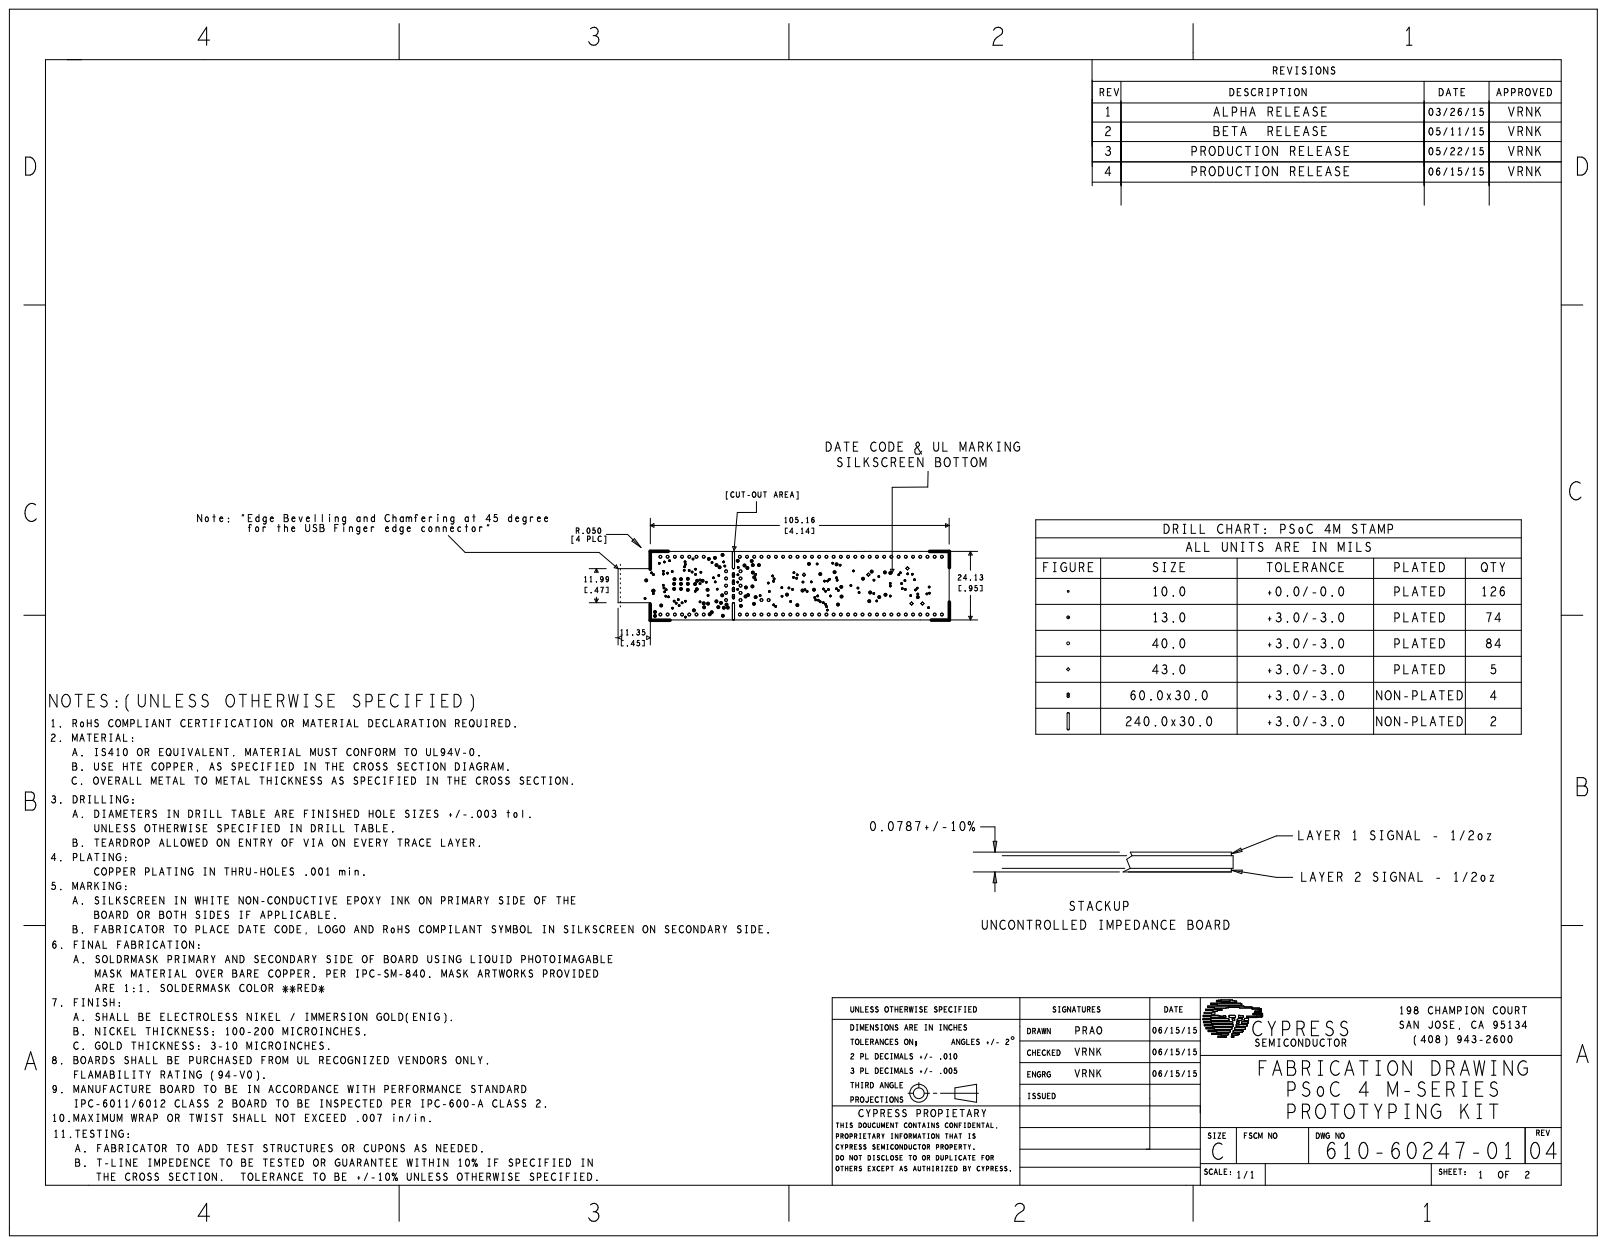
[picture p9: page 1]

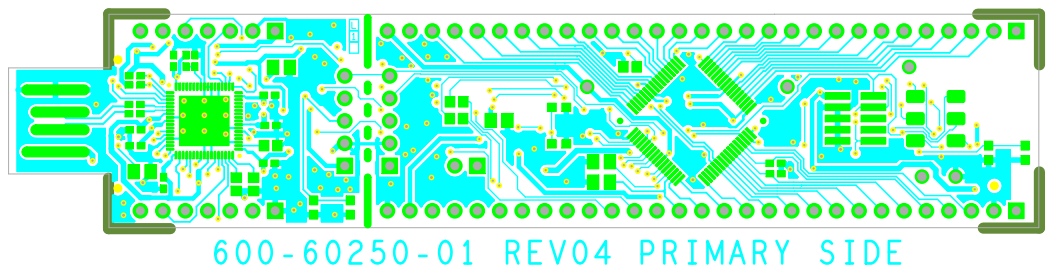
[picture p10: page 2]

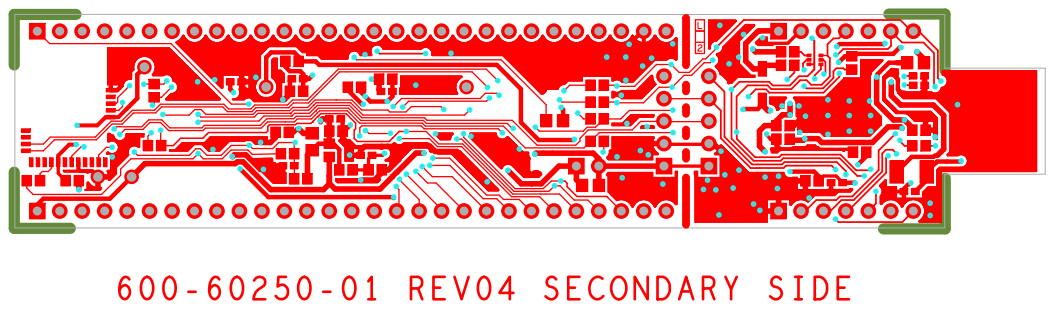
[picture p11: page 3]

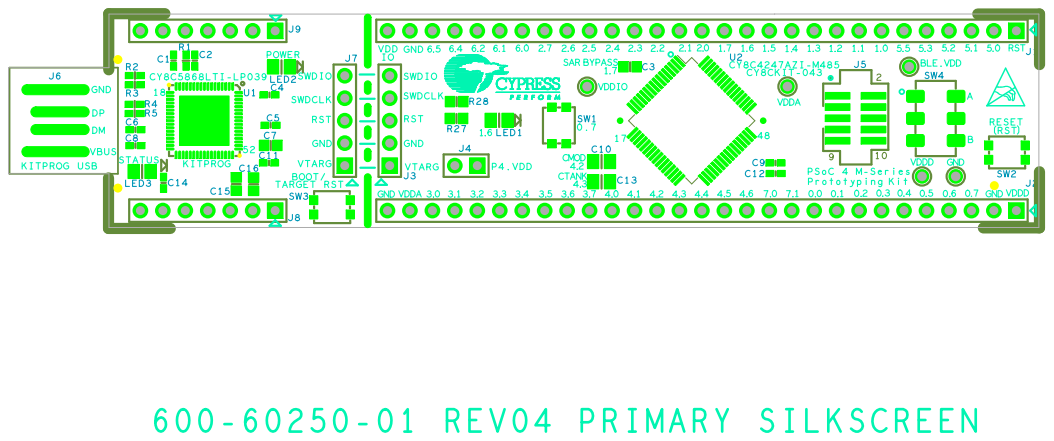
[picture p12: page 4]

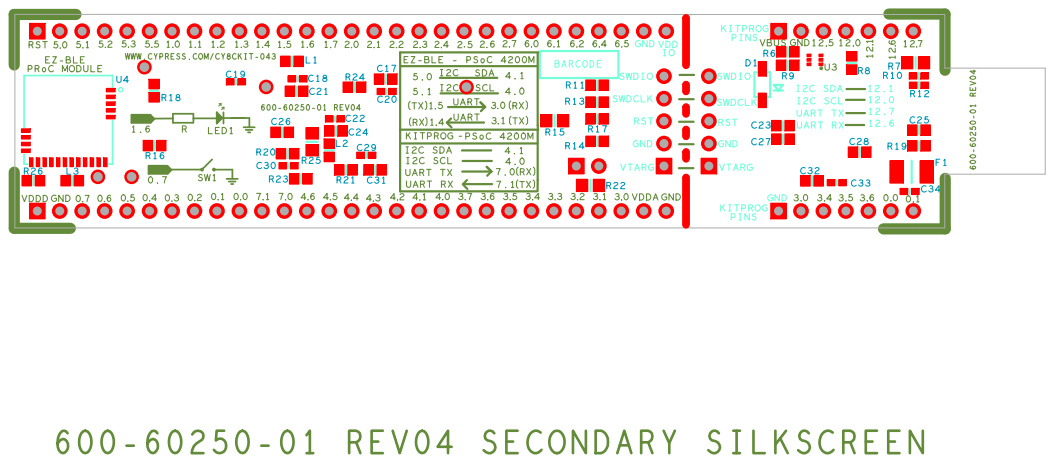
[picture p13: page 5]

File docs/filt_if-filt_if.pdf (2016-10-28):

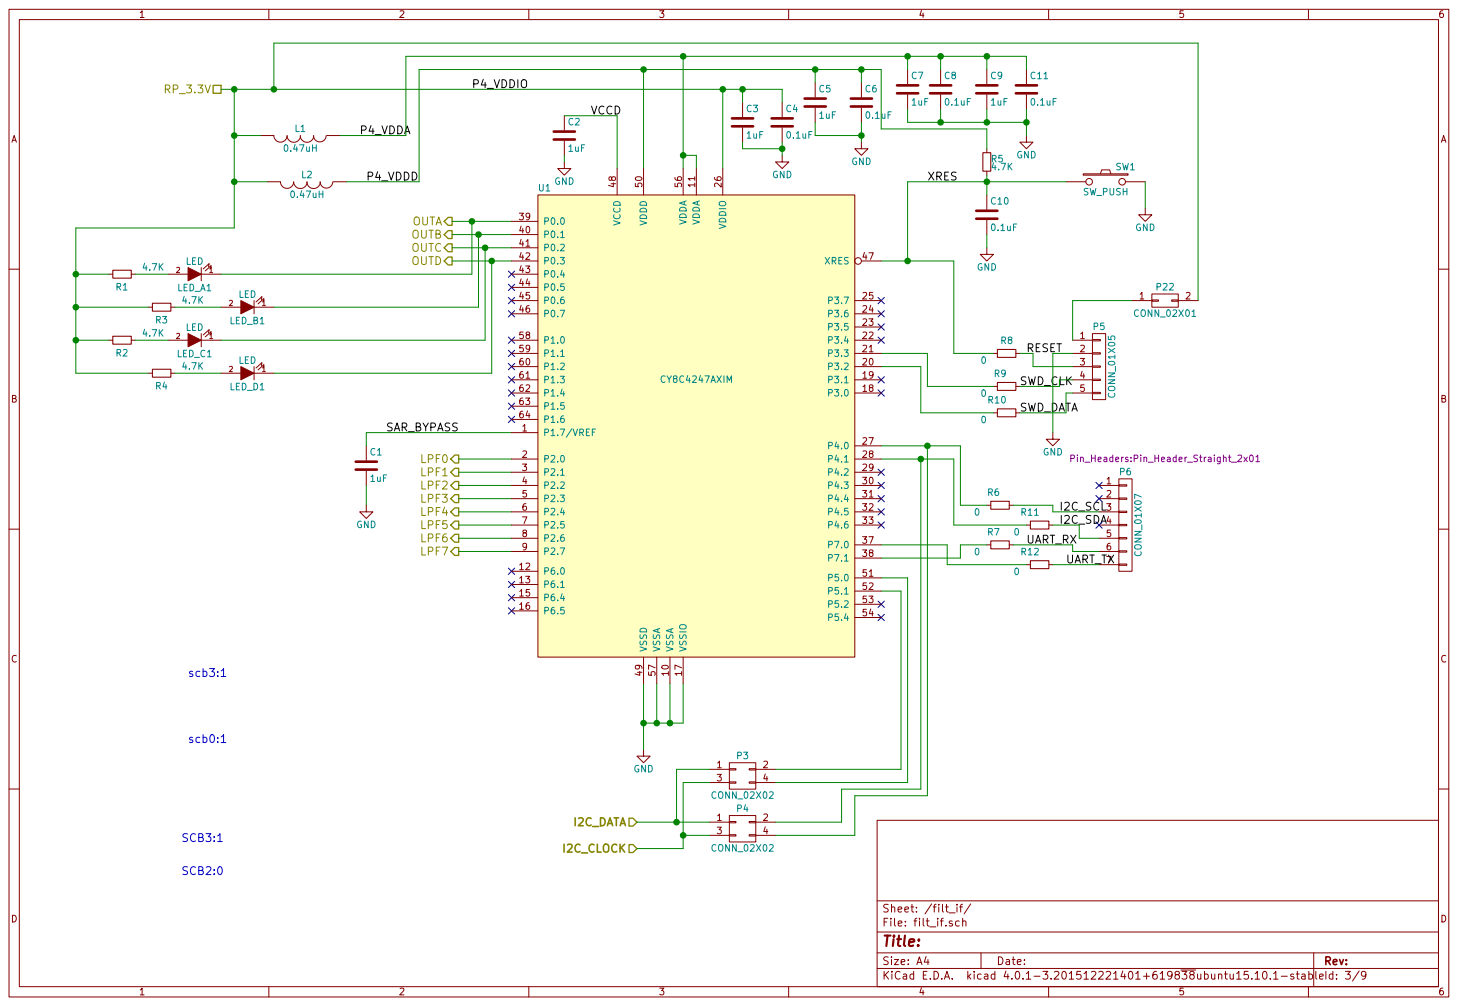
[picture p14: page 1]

VCCD | C3

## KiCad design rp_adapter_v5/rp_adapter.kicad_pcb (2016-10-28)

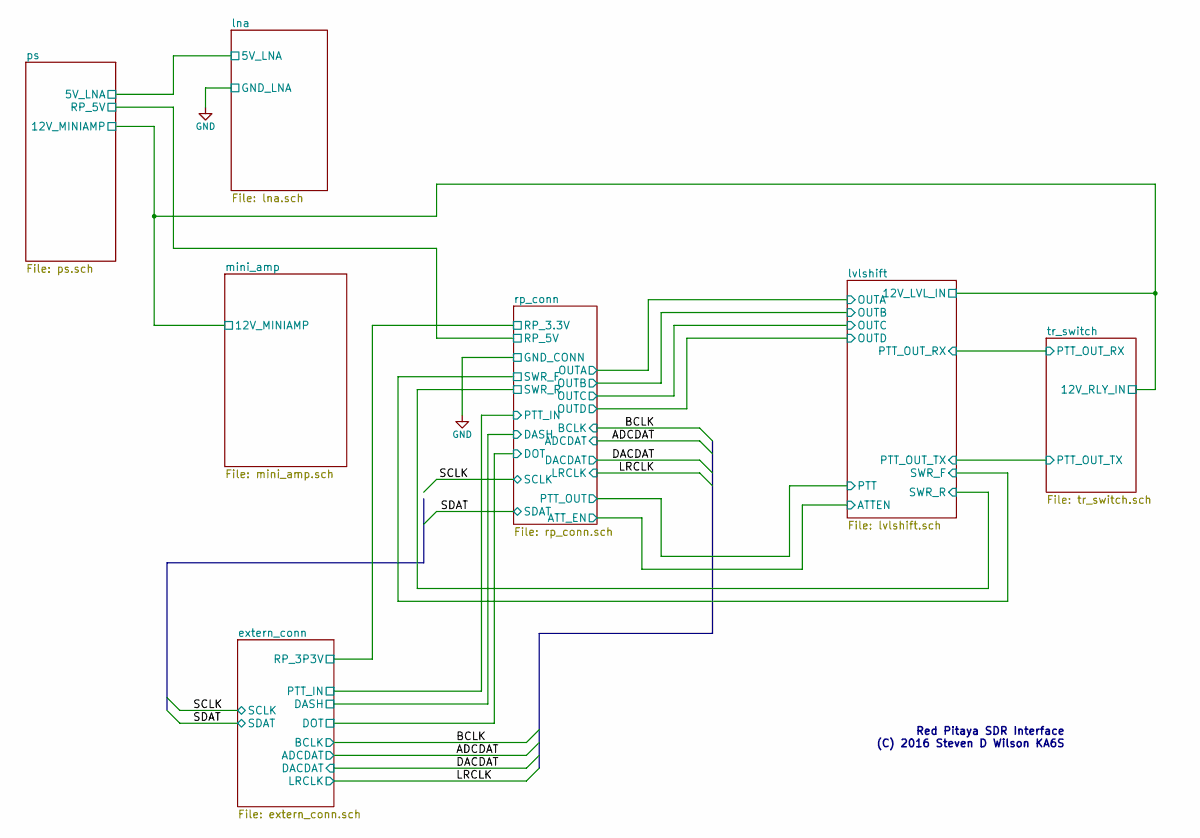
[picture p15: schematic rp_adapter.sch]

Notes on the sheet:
Red Pitaya SDR Interface (C) 2016 Steven D Wilson KA6S

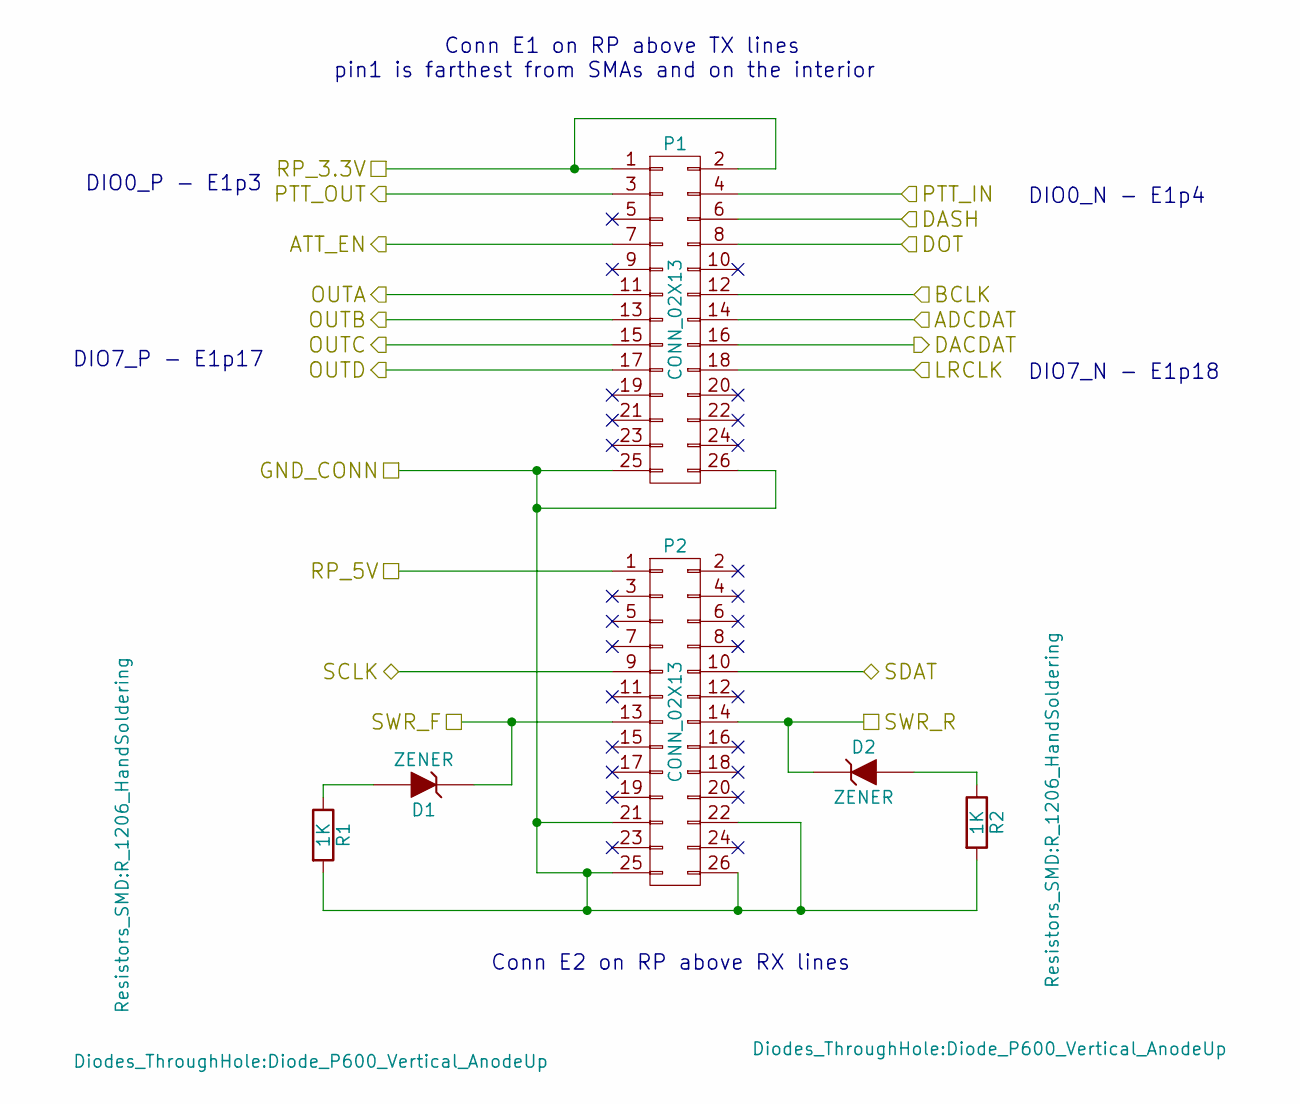
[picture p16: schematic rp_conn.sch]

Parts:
D1, D2: ZENER; Diode_P600_Vertical_AnodeUp
P1, P2: CONN_02X13; Pin_Header_Straight_2x13
R1, R2: 1K; R_1206_HandSoldering

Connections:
/extern_conn/ADCDAT: P1.14; also elsewhere on the board
/extern_conn/BCLK: P1.12; also elsewhere on the board
/extern_conn/DACDAT: P1.16; also elsewhere on the board
/extern_conn/DASH: P1.6; also elsewhere on the board
/extern_conn/DOT: P1.8; also elsewhere on the board
/extern_conn/LRCLK: P1.18; also elsewhere on the board
/extern_conn/PTT_IN: P1.4; also elsewhere on the board
/extern_conn/SCLK: P2.9; also elsewhere on the board
/extern_conn/SDAT: P2.10; also elsewhere on the board
/lvlshift/ATTEN: P1.7; also elsewhere on the board
/lvlshift/OUTA: P1.11; also elsewhere on the board
/lvlshift/OUTB: P1.13; also elsewhere on the board
/lvlshift/OUTC: P1.15; also elsewhere on the board
/lvlshift/OUTD: P1.17; also elsewhere on the board
/lvlshift/PTT: P1.3; also elsewhere on the board
/ps/RP_5V: P2.1; also elsewhere on the board
/rp_conn/RP_3.3V: P1.1, P1.2; also elsewhere on the board
/rp_conn/SWR_F: D1.1 (K), P2.13; also elsewhere on the board
/rp_conn/SWR_R: D2.1 (K), P2.14; also elsewhere on the board
GND: P1.25, P1.26, P2.21, P2.22, P2.25, P2.26, R1.2, R2.2; also elsewhere on the board
unnamed: D1.2 (A), R1.1
unnamed: D2.2 (A), R2.1

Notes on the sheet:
Conn E1 on RP above TX lines
Conn E2 on RP above RX lines
pin1 is farthest from SMAs and on the interior
DIO0_P - E1p3
DIO7_P - E1p17
DIO0_N - E1p4
DIO7_N - E1p18

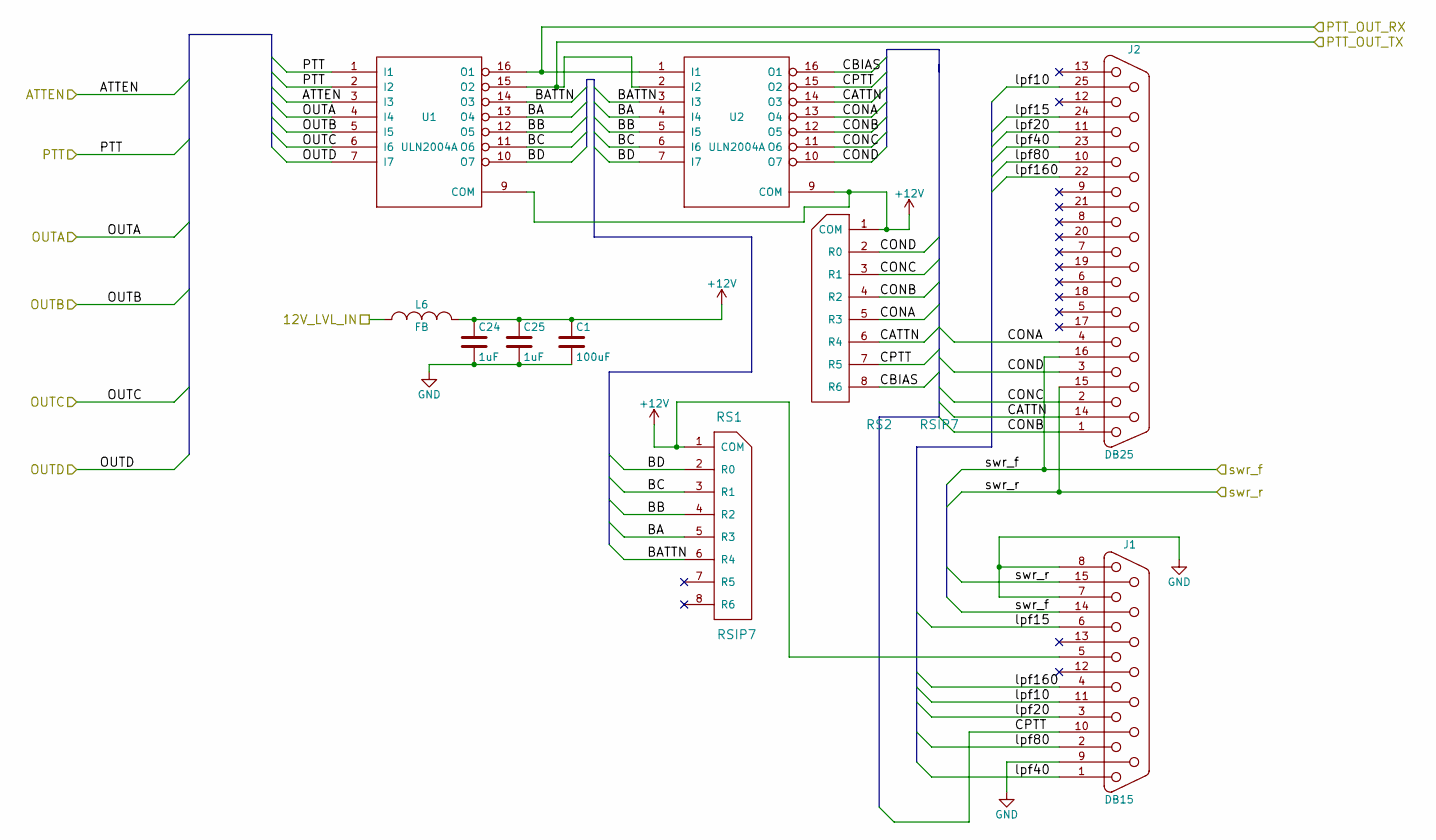
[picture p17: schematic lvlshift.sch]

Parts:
C1: 100uF; C_1210_HandSoldering
C24, C25: 1uF; C_1210_HandSoldering
J1: DB15; DB15FC
J2: DB25; DB25FC
L6: FB
RS1, RS2: RSIP7; Pin_Header_Straight_1x08
U1, U2: ULN2004A; DIP-16_W7.62mm

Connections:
+12V: C1.1, C24.1, C25.1, J1.5, L6.2, RS1.1 (COM), RS2.1 (COM), U1.9 (COM), U2.9 (COM)
/lvlshift/12V_LVL_IN: L6.1; also elsewhere on the board
/lvlshift/ATTEN: U1.3 (I3); also elsewhere on the board
/lvlshift/BA: RS1.5 (R3), U1.13 (O4), U2.4 (I4)
/lvlshift/BATTN: RS1.6 (R4), U1.14 (O3), U2.3 (I3)
/lvlshift/BB: RS1.4 (R2), U1.12 (O5), U2.5 (I5)
/lvlshift/BC: RS1.3 (R1), U1.11 (O6), U2.6 (I6)
/lvlshift/BD: RS1.2 (R0), U1.10 (O7), U2.7 (I7)
/lvlshift/CATTN: J2.14, RS2.6 (R4), U2.14 (O3)
/lvlshift/CBIAS: RS2.8 (R6), U2.16 (O1)
/lvlshift/CONA: J2.4, RS2.5 (R3), U2.13 (O4)
/lvlshift/CONB: J2.1, RS2.4 (R2), U2.12 (O5)
/lvlshift/CONC: J2.2, RS2.3 (R1), U2.11 (O6)
/lvlshift/COND: J2.3, RS2.2 (R0), U2.10 (O7)
/lvlshift/CPTT: J1.10, RS2.7 (R5), U2.15 (O2)
/lvlshift/OUTA: U1.4 (I4); also elsewhere on the board
/lvlshift/OUTB: U1.5 (I5); also elsewhere on the board
/lvlshift/OUTC: U1.6 (I6); also elsewhere on the board
/lvlshift/OUTD: U1.7 (I7); also elsewhere on the board
/lvlshift/PTT: U1.1 (I1), U1.2 (I2); also elsewhere on the board
/lvlshift/PTT_OUT_RX: U1.16 (O1), U2.1 (I1); also elsewhere on the board
/lvlshift/PTT_OUT_TX: U1.15 (O2), U2.2 (I2); also elsewhere on the board
/lvlshift/lpf10: J1.11 (P111), J2.25
/lvlshift/lpf15: J1.6, J2.24
/lvlshift/lpf20: J1.3, J2.11
/lvlshift/lpf40: J1.1, J2.23
/lvlshift/lpf80: J1.2, J2.10
/lvlshift/lpf160: J1.4, J2.22
/rp_conn/SWR_F: J1.14, J2.16; also elsewhere on the board
/rp_conn/SWR_R: J1.15, J2.15; also elsewhere on the board
GND: C1.2, C24.2, C25.2, J1.7, J1.8, J1.9, U1.8 (GND), U2.8 (GND); also elsewhere on the board

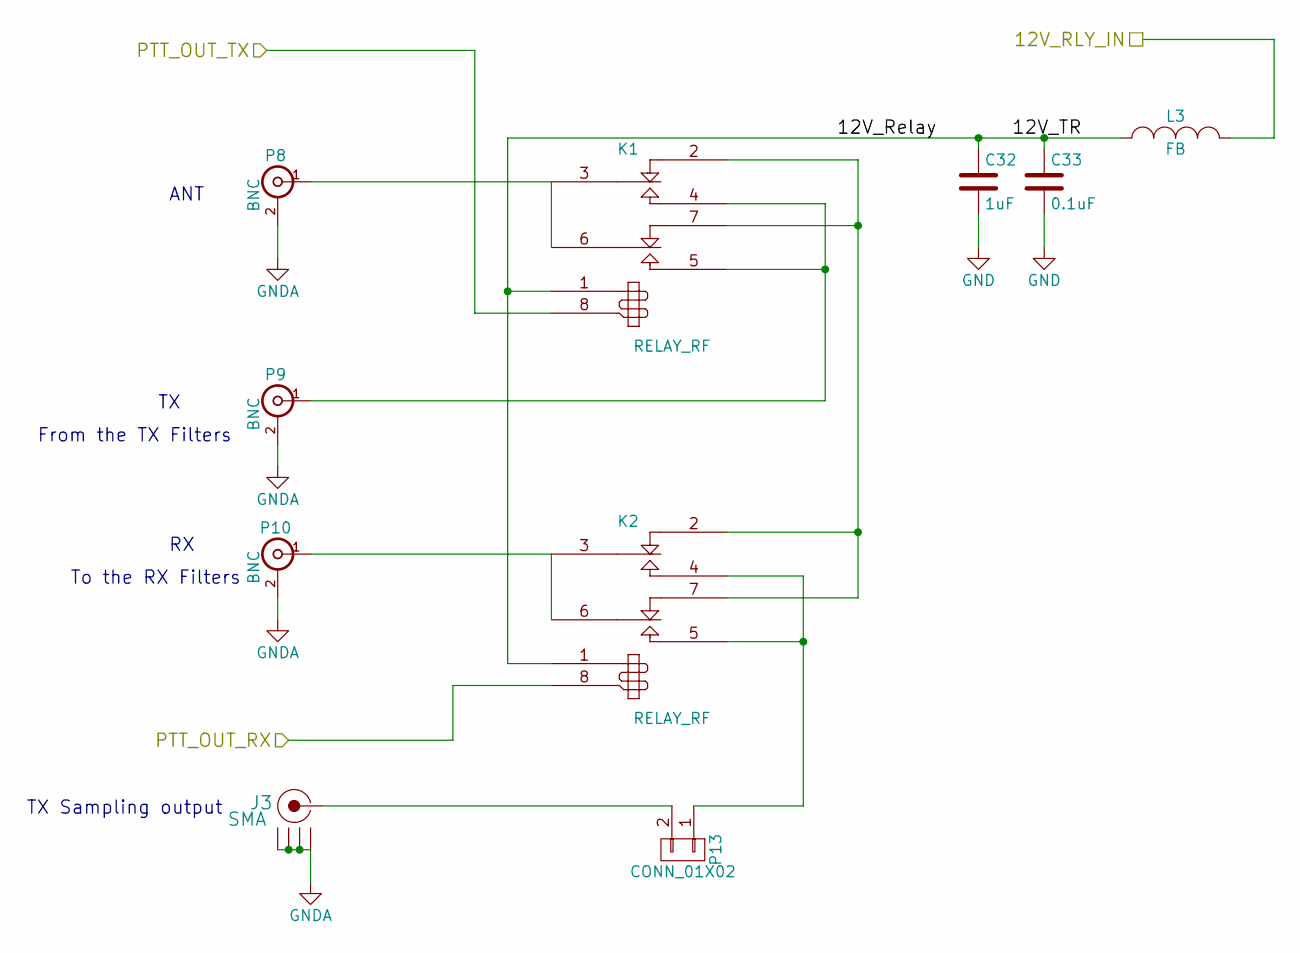
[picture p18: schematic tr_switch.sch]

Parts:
C32: 1uF; C_1210_HandSoldering
C33: 0.1uF; C_1206_HandSoldering
J3: SMA; SMA_F_RA
K1, K2: RELAY_RF; RF_RELAY
L3: FB
P8, P9, P10: BNC; BNC_VERTICAL
P13: CONN_01X02; Pin_Header_Straight_1x02

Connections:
/lvlshift/12V_LVL_IN: L3.2; also elsewhere on the board
/lvlshift/PTT_OUT_RX: K2.8 (9); also elsewhere on the board
/lvlshift/PTT_OUT_TX: K1.8 (9); also elsewhere on the board
/tr_switch/12V_Relay: C32.1, C33.1, K1.1 (8), K2.1 (8), L3.1
GND: C32.2, C33.2; also elsewhere on the board
GNDA: J3.2 (GND1), J3.3 (GND2), J3.4 (GND3), J3.5 (GND4), P8.2 (Ext), P9.2 (Ext), P10.2 (Ext)
unnamed: J3.1 (RF), P13.2
unnamed: K1.2 (R2), K1.7 (R1), K2.2 (R2), K2.7 (R1)
unnamed: K1.3 (C2), K1.6 (C1), P8.1 (In)
unnamed: K1.4 (T2), K1.5 (T1), P9.1 (In)
unnamed: K2.3 (C2), K2.6 (C1), P10.1 (In)
unnamed: K2.4 (T2), K2.5 (T1), P13.1

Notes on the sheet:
ANT
To the RX Filters
From the TX Filters
TX Sampling output

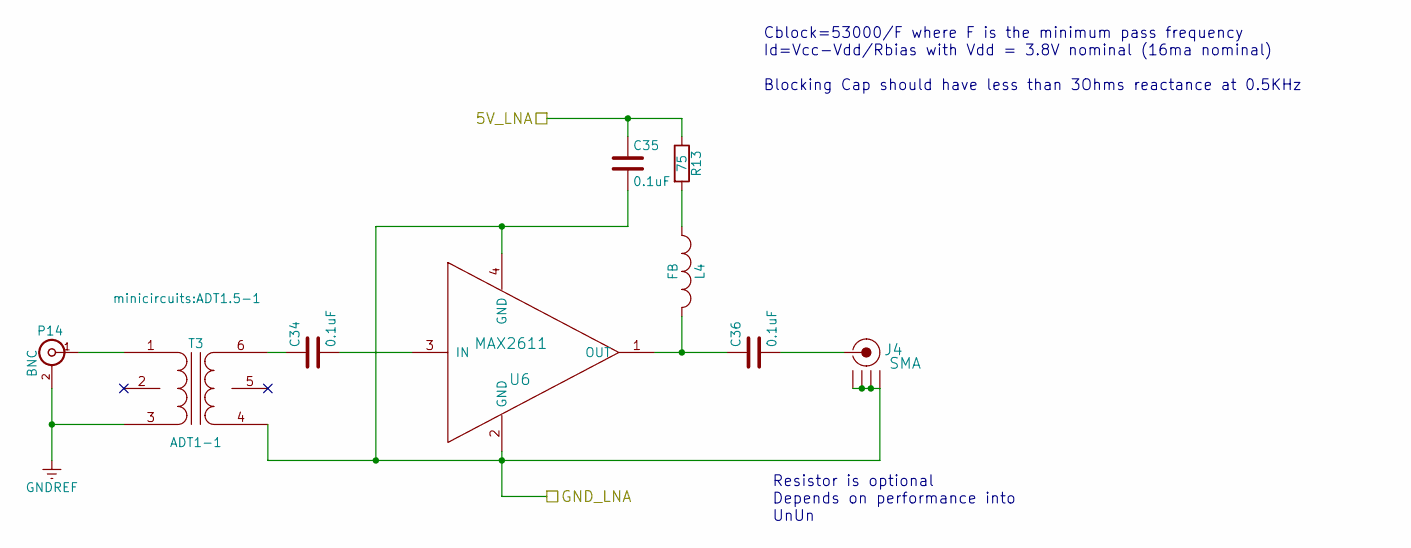
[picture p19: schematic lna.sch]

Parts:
C34, C35, C36: 0.1uF; C_1206_HandSoldering
J4: SMA; SMA_F_RA
L4: FB
P14: BNC; BNC_VERTICAL
R13: 75; R_1206_HandSoldering
T3: ADT1-1; ADT1.5-1
U6: MAX2611; SOT-143_Handsoldering

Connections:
/lna/5V_LNA: C35.1, R13.1; also elsewhere on the board
GND: C35.2, J4.2 (GND1), J4.3 (GND2), J4.4 (GND3), J4.5 (GND4), T3.4 (S1), U6.2 (GND), U6.4 (GND); also elsewhere on the board
GNDREF: P14.2 (Ext), T3.3 (PR2)
unnamed: C34.1, T3.6 (S2)
unnamed: C34.2, U6.3 (IN)
unnamed: C36.1, L4.2, U6.1 (OUT)
unnamed: C36.2, J4.1 (RF)
unnamed: L4.1, R13.2
unnamed: P14.1 (In), T3.1 (PR1)

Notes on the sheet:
Cblock=53000/F where F is the minimum pass frequency Id=Vcc-Vdd/Rbias with Vdd = 3.8V nominal (16ma nominal) Blocking Cap should have less than 3Ohms reactance at 0.5KHz
Resistor is optional Depends on performance into UnUn

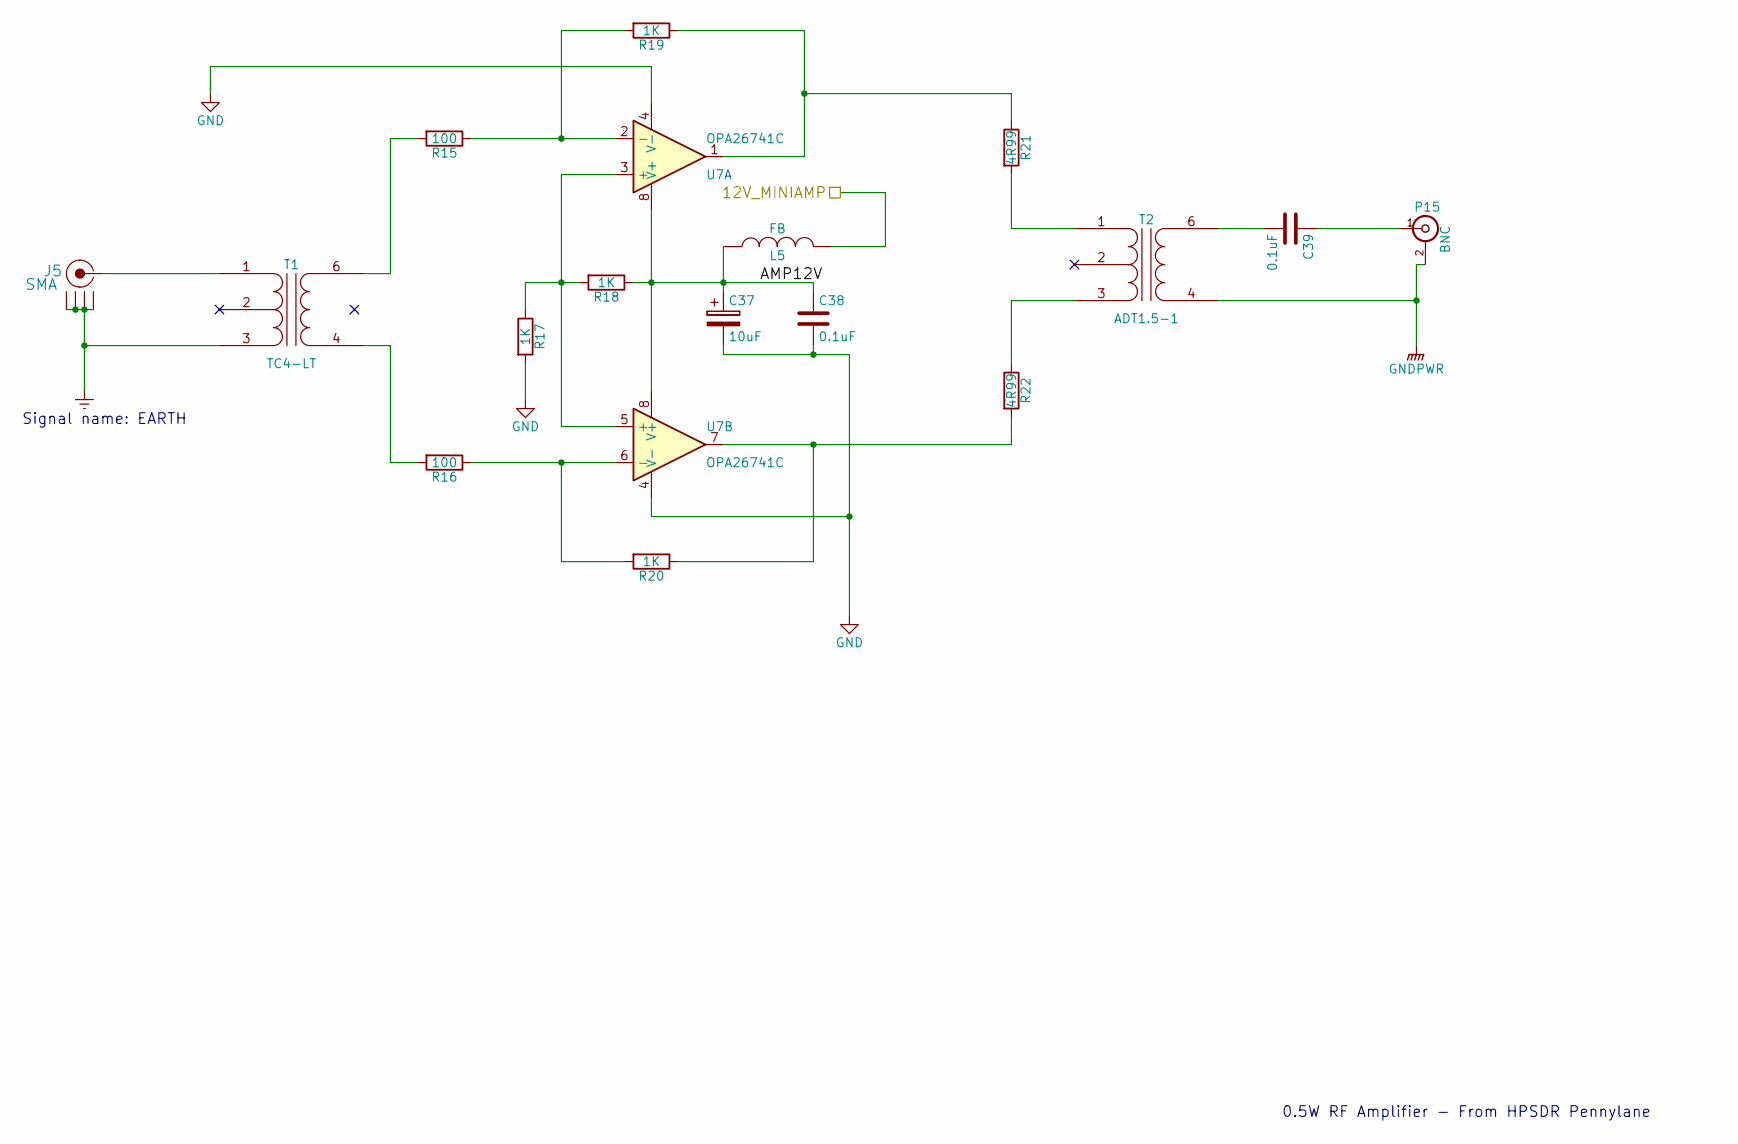
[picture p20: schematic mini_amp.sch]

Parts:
C37: 10uF; SMD-1210_Pol
C38, C39: 0.1uF; C_1206_HandSoldering
J5: SMA; SMA_F_RA
L5: FB
P15: BNC; BNC_VERTICAL
R15, R16: 100; Resistor_Horizontal_RM7mm
R17, R18, R19, R20: 1K; Resistor_Horizontal_RM7mm
R21, R22: 4R99; Resistor_Horizontal_RM7mm
T1: TC4-LT; TC4-1T
T2: ADT1.5-1
U7: OPA26741C; SOIC-8-N

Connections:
/lvlshift/12V_LVL_IN: L5.2; also elsewhere on the board
/mini_amp/AMP12V: C37.1, C38.1, L5.1, R18.1, U7.8 (V+)
Earth: J5.2 (GND1), J5.3 (GND2), J5.4 (GND3), J5.5 (GND4), T1.3 (PR2)
GND: C37.2, C38.2, R17.2, U7.4 (V-); also elsewhere on the board
GNDPWR: P15.2 (Ext), T2.4 (S1)
unnamed: C39.1, P15.1 (In)
unnamed: C39.2, T2.6 (S2)
unnamed: J5.1 (RF), T1.1 (PR1)
unnamed: R15.1, R19.2, U7.2 (-)
unnamed: R15.2, T1.6 (S2)
unnamed: R16.1, R20.2, U7.6 (-)
unnamed: R16.2, T1.4 (S1)
unnamed: R17.1, R18.2, U7.3 (+), U7.5 (+)
unnamed: R19.1, R21.1, U7.1
unnamed: R20.1, R22.2, U7.7
unnamed: R21.2, T2.1 (PR1)
unnamed: R22.1, T2.3 (PR2)

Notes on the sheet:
0.5W RF Amplifier - From HPSDR Pennylane
Signal name: EARTH

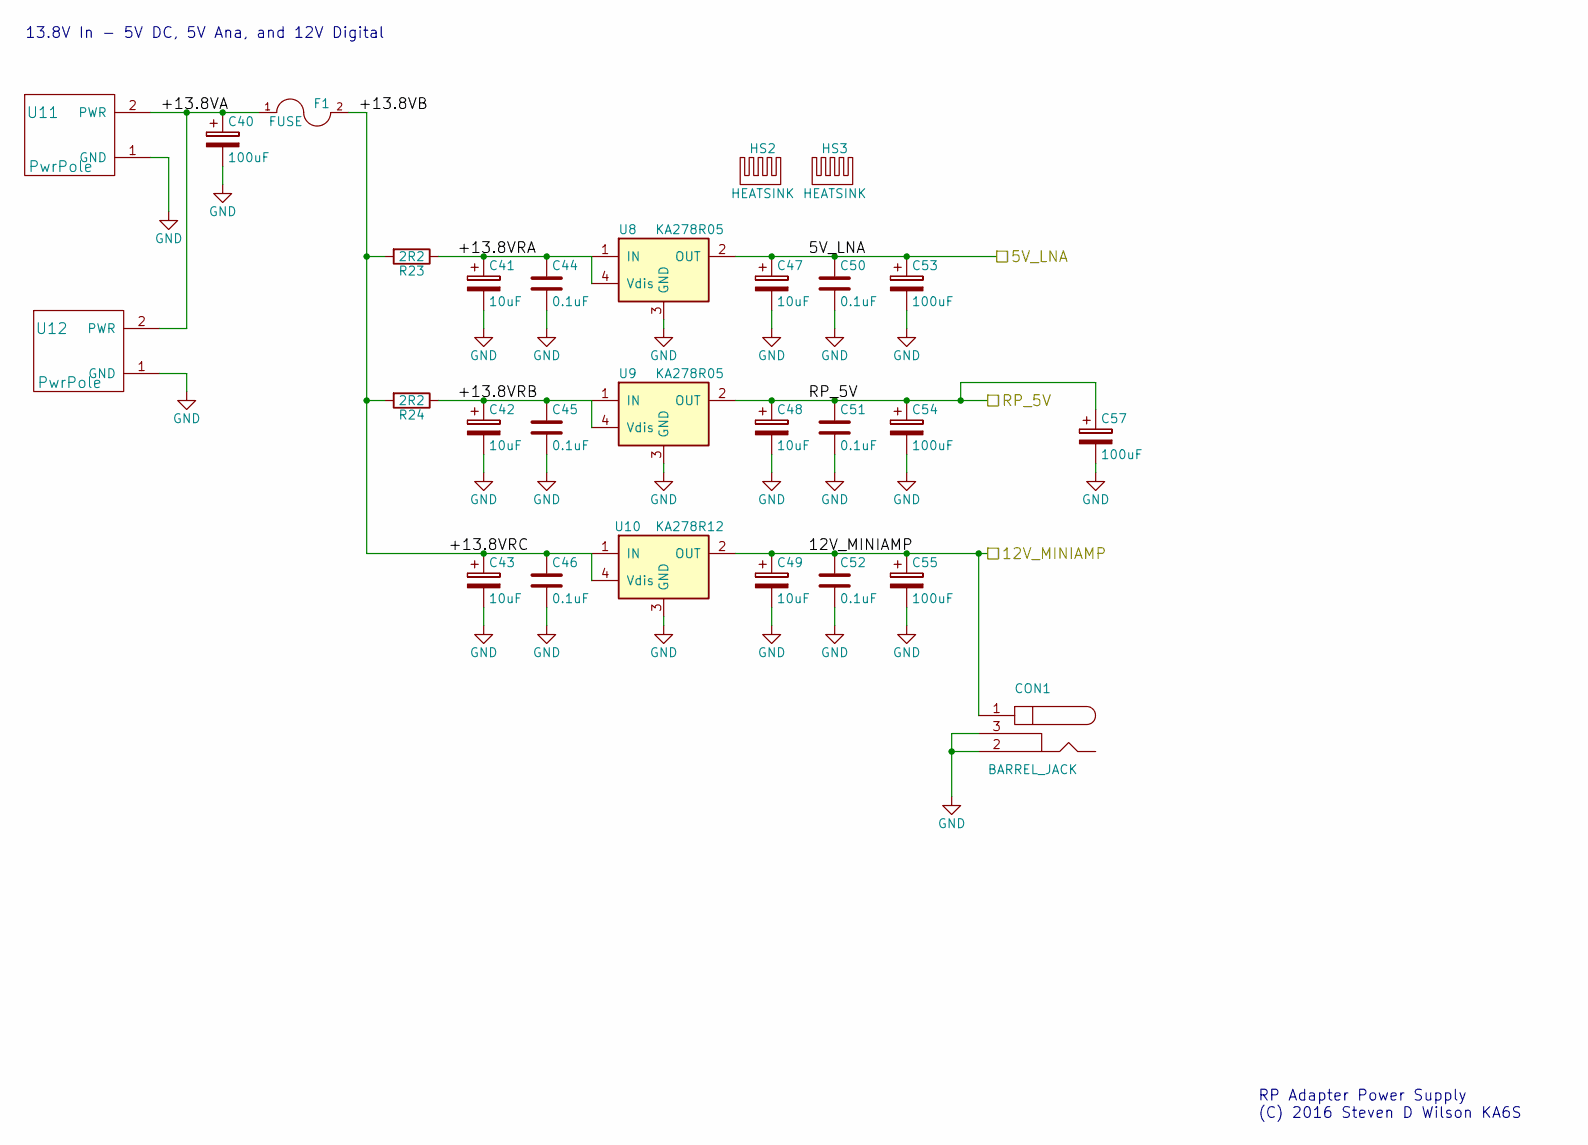
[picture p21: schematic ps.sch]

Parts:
C40, C53, C54, C55, C57: 100uF; SMD-1210_Pol
C41, C42, C43: 10uF; SMD-1210_Pol
C44, C45, C46, C50, C51, C52: 0.1uF; C_1206_HandSoldering
C47, C48, C49: 10uF; SMD-2010_Pol
CON1: BARREL_JACK
F1: FUSE; Fuse_SMD1206_HandSoldering
HS2, HS3: HEATSINK; Heatsink_Fischer_SK129-STS_42x25mm_2xDrill2.5mm
R23, R24: 2R2; RES_10W
U8, U9: KA278R05; TO-220_4pin_vertical
U10: KA278R12; TO-220_4pin_vertical
U11, U12: PwrPole; RA_POWER_POLE

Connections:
/lna/5V_LNA: C47.1, C50.1, C53.1, U8.2 (OUT); also elsewhere on the board
/lvlshift/12V_LVL_IN: C49.1, C52.1, C55.1, CON1.1, U10.2 (OUT); also elsewhere on the board
/ps/+13.8VA: C40.1, F1.1, U11.2 (PWR), U12.2 (PWR)
/ps/+13.8VB: C43.1, C46.1, F1.2, R23.2, R24.2, U10.1 (IN), U10.4 (Vdis)
/ps/+13.8VRA: C41.1, C44.1, R23.1, U8.1 (IN), U8.4 (Vdis)
/ps/+13.8VRB: C42.1, C45.1, R24.1, U9.1 (IN), U9.4 (Vdis)
/ps/RP_5V: C48.1, C51.1, C54.1, C57.1, U9.2 (OUT); also elsewhere on the board
GND: C40.2, C41.2, C42.2, C43.2, C44.2, C45.2, C46.2, C47.2, C48.2, C49.2, C50.2, C51.2, C52.2, C53.2, C54.2, C55.2, C57.2, CON1.2, CON1.3, U8.3 (GND), U9.3 (GND), U10.3 (GND), U11.1 (GND), U12.1 (GND); also elsewhere on the board

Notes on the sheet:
13.8V In - 5V DC, 5V Ana, and 12V Digital
RP Adapter Power Supply (C) 2016 Steven D Wilson KA6S

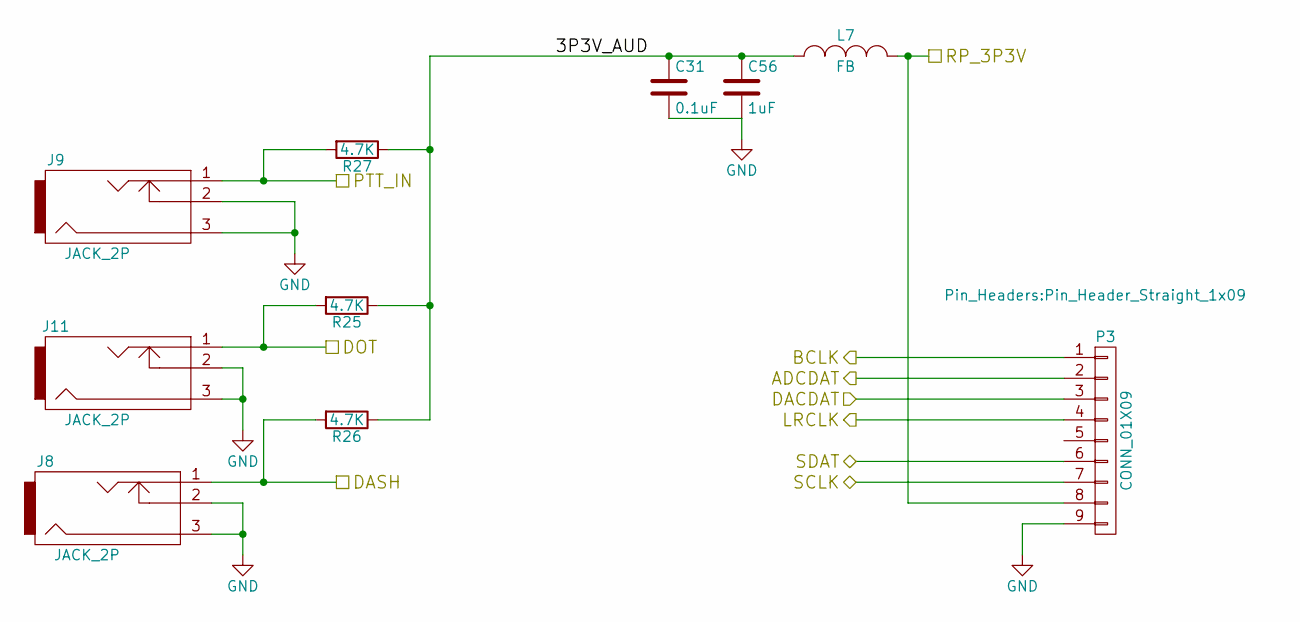
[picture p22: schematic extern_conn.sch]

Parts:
C31: 0.1uF; C_1206_HandSoldering
C56: 1uF; C_1210_HandSoldering
J8, J9, J11: JACK_2P; RA_3p5_audio_jack
L7: FB
P3: CONN_01X09; Pin_Header_Straight_1x09
R25, R26, R27: 4.7K; R_1206_HandSoldering

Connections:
/extern_conn/3P3V_AUD: C31.1, C56.1, L7.1, R25.1, R26.1, R27.1
/extern_conn/ADCDAT: P3.2; also elsewhere on the board
/extern_conn/BCLK: P3.1; also elsewhere on the board
/extern_conn/DACDAT: P3.3; also elsewhere on the board
/extern_conn/DASH: J8.1, R26.2; also elsewhere on the board
/extern_conn/DOT: J11.1, R25.2; also elsewhere on the board
/extern_conn/LRCLK: P3.4; also elsewhere on the board
/extern_conn/PTT_IN: J9.1, R27.2; also elsewhere on the board
/extern_conn/SCLK: P3.7; also elsewhere on the board
/extern_conn/SDAT: P3.6; also elsewhere on the board
/rp_conn/RP_3.3V: L7.2, P3.8; also elsewhere on the board
GND: C31.2, C56.2, J8.2, J8.3, J9.2, J9.3, J11.2, J11.3, P3.9; also elsewhere on the board

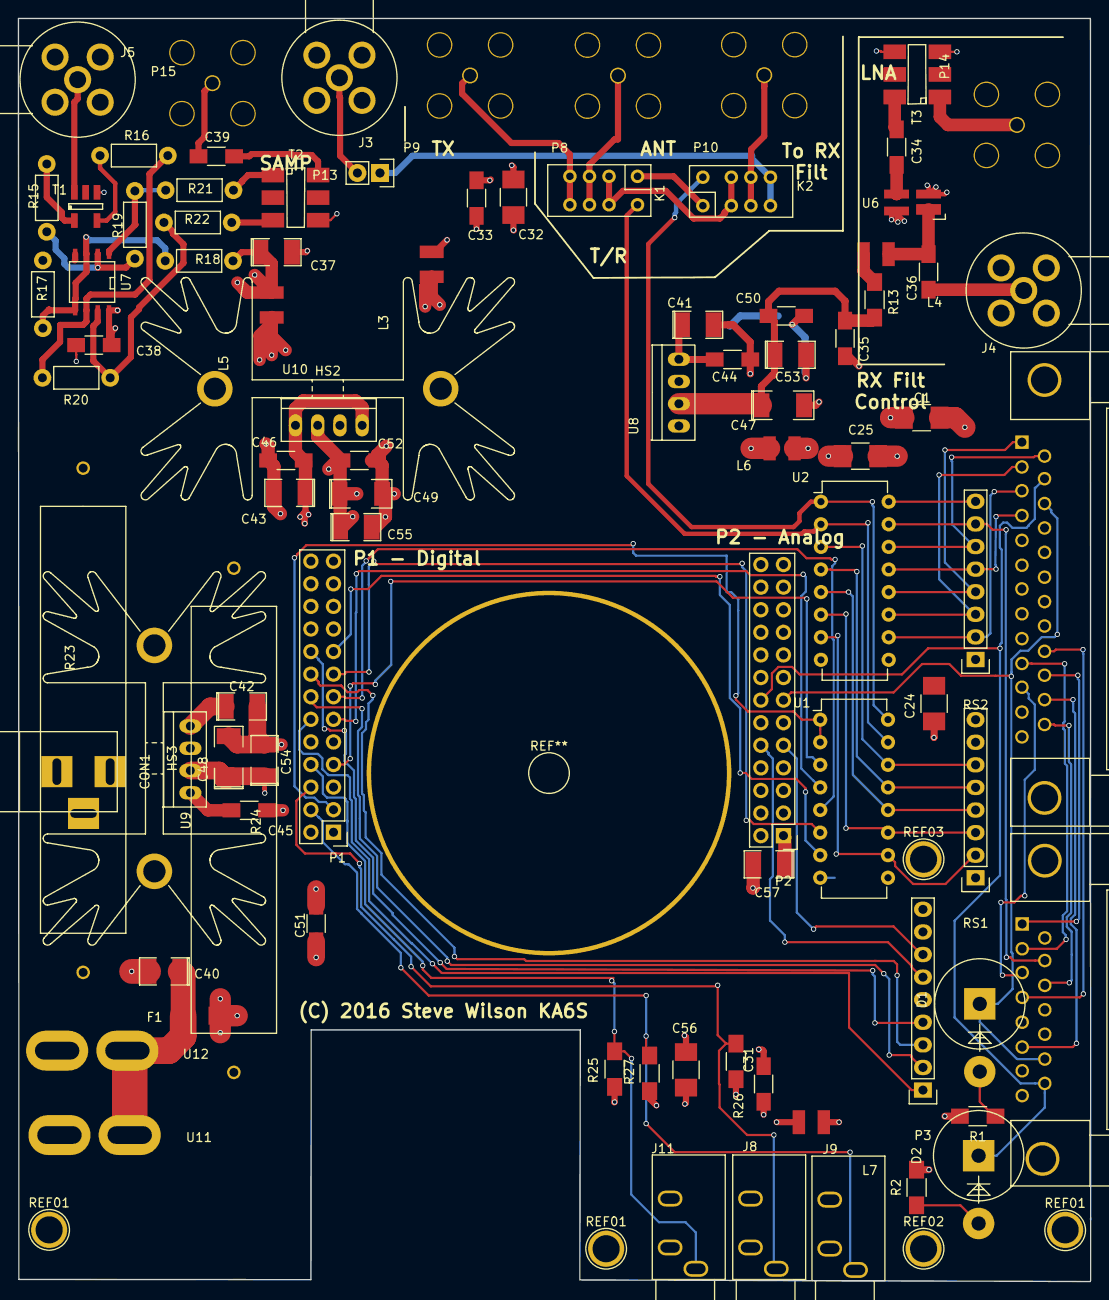
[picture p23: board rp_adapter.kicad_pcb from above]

Board: 4 copper layers, 120.6 x 142.0 mm, 95 parts (0 on the bottom side), 80 nets.

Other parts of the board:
REF01, REF01#2, REF01#3, REF02, REF03: 1pin

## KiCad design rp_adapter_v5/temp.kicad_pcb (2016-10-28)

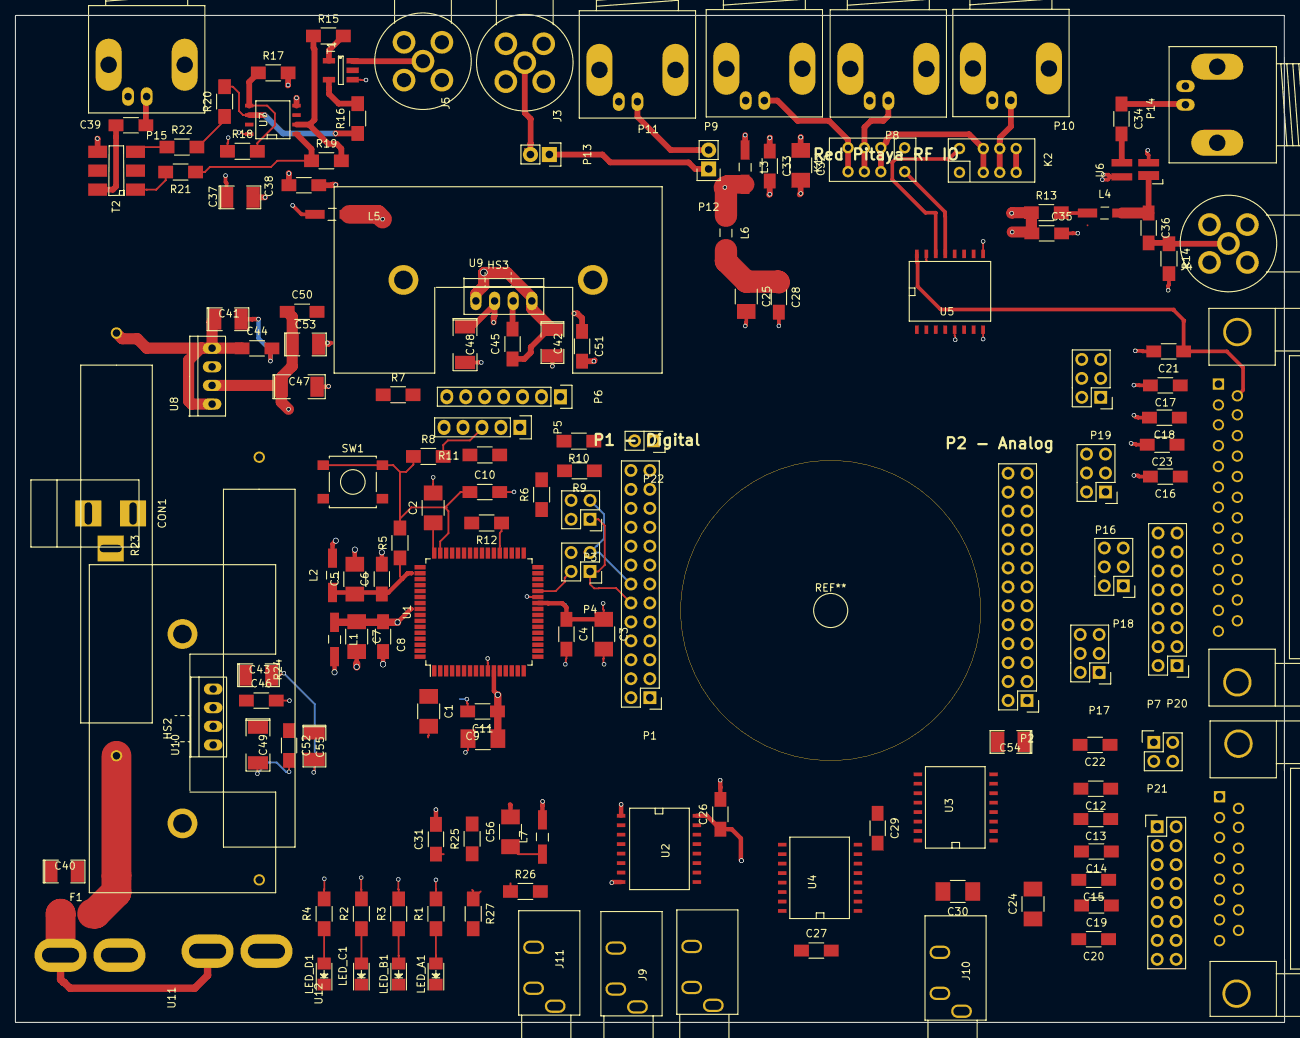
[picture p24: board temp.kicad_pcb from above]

Board: 4 copper layers, 170.2 x 135.1 mm, 146 parts (0 on the bottom side), 122 nets.

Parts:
C1, C2, C3, C5, C7, C9, C24, C25, C32, C56: 1uF; C_1210_HandSoldering
C4, C6, C8, C10, C11, C26, C27, C28, C29, C31, C33, C34, C35, C36, C38, C39, C44, C45, C46, C50, C51, C52: 0.1uF; C_1206_HandSoldering
C12, C13, C14, C15, C16, C17, C18, C19, C20, C21, C22, C23: 100pF; C_1206_HandSoldering
C30: 10uF; C_1210_HandSoldering
C37, C41, C42, C43: 10uF; SMD-1210_Pol
C40, C53, C54, C55: 100uF; SMD-1210_Pol
C47, C48, C49: 10uF; SMD-2010_Pol
CON1: BARREL_JACK
F1: FUSE; Fuse_SMD1206_HandSoldering
HS2, HS3: HEATSINK; Heatsink-TO220
J1: DB15; DB15FC
J2: DB25; DB25FC
J3, J4, J5: SMA; SMA_F_RA
J8, J9, J10, J11: JACK_2P; RA_3p5_audio_jack
K1, K2: RELAY_RF; RF_RELAY
L1, L2: 0.47uH; Choke_SMD_1206_Handsoldering
L3, L4, L5, L6, L7: FB; Choke_SMD_1206_Handsoldering
LED_A1: LED; LED_1206
LED_B1: LED; LED_1206
LED_C1: LED; LED_1206
LED_D1: LED; LED_1206
P1, P2: CONN_02X13; Pin_Header_Straight_2x13
P3, P4, P7: CONN_02X02; Pin_Header_Straight_2x02
P5: CONN_01X05; Pin_Header_Straight_1x05
P6: CONN_01X07; Pin_Header_Straight_1x07
P8, P9, P10, P11, P14, P15: BNC; BNC_Socket_TYCO-AMP_LargePads
P12, P13: CONN_01X02; Pin_Header_Straight_1x02
P16, P17, P18, P19: CONN_02X03; Pin_Header_Straight_2x03
P20, P21: CONN_02X08; Pin_Header_Straight_2x08
P22: CONN_02X01; Pin_Header_Straight_2x01
R1, R2, R3, R4, R5, R25, R26, R27: 4.7K; R_1206_HandSoldering
R6, R7, R8, R9, R10, R11, R12: 0; R_1206_HandSoldering
R13: 75; R_1206_HandSoldering
R14: 50; R_1206_HandSoldering
R15, R16: 100; R_1206_HandSoldering
R17, R18, R19, R20: 1K; R_1206_HandSoldering
R21, R22: 4R99; R_1206_HandSoldering
R23, R24: 2R2; RES_10W
SW1: SW_PUSH; SW_SPST_B3S-1000
T1: TC4-LT; TC4-1T
T2: ADT1.5-1
U1: CY8C4247AXIM; LQFP-64_14x14mm_Pitch0.8mm
U2, U3, U4: 4504; SO-16-W
U5: ULN2003; SO-16-W
U6: MAX2611; SOT-143_Handsoldering
U7: OPA26741C; SOIC-8-N
U8, U9: KA278R05; TO-220_4pin_vertical
U10: KA278R12; TO-220_4pin_vertical
U11, U12: PwrPole; RA_POWER_POLE

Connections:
+12V: C24.1, C25.1, C26.1, C27.1, C28.1, C29.1, J1.5, L6.2, U2.16, U3.16, U4.16
/extern_conn/AUDIO_IN: C30.1, P16.5, P17.5, P18.5, P19.5
/extern_conn/DASH: J8.1, P1.6, R26.2
/extern_conn/DOT: J11.1, P1.8, R25.2
/extern_conn/PTT_IN: J9.1, P1.4, R27.2
/filt_if/I2C_CLOCK: P1.14, P3.3, P4.3
/filt_if/I2C_DATA: P1.12, P3.1, P4.1
/filt_if/I2C_SCL: P6.3, R6.2
/filt_if/I2C_SDA: P6.5, R11.2
/filt_if/LPF0: U1.2, U2.14
/filt_if/LPF1: U1.3, U3.14
/filt_if/LPF2: U1.4, U2.5
/filt_if/LPF3: U1.5, U3.5
/filt_if/LPF4: U1.6, U2.3
/filt_if/LPF5: U1.7, U3.3
/filt_if/LPF6: U1.8, U4.3
/filt_if/LPF7: U1.9, U4.5
/filt_if/OUTA: LED_A1.1, U1.39, U2.9
/filt_if/OUTB: LED_B1.1, U1.40, U3.9
/filt_if/OUTC: LED_C1.1, U1.41, U2.11
/filt_if/OUTD: LED_D1.1, U1.42, U3.11
/filt_if/P4_VDDA: C7.1, C8.1, C9.1, C11.1, L1.1, U1.11, U1.56
/filt_if/P4_VDDD: C5.1, C6.1, L2.1, R5.1, U1.50
/filt_if/RESET: P5.3, R8.2
/filt_if/SAR_BYPASS: C1.1, U1.1
/filt_if/SWD_CLK: P5.4, R9.2
/filt_if/SWD_DATA: P5.5, R10.2
/filt_if/UART_RX: P6.6, R7.2
/filt_if/UART_TX: P6.7, R12.2
/filt_if/VCCD: C2.1, U1.48
/filt_if/XRES: C10.1, R5.2, R8.1, SW1.1, U1.47
/lna/5V_LNA: C35.1, C47.1, C50.1, C53.1, R13.1, U8.2
/lvlshift/12V_LVL_IN: C49.1, C52.1, C55.1, CON1.1, L3.2, L5.2, L6.1, U10.2
/lvlshift/ATTEN: P1.5, U2.7
/lvlshift/PTT: P1.3, U3.7
/lvlshift/PTT_OUT_RX: K2.8, U5.14
/lvlshift/PTT_OUT_TX: K1.8, U5.13
/lvlshift/SWR_F: P16.1, P17.1, P18.1, P19.1, P21.13
/lvlshift/lpf10o: J2.25, P20.1
/lvlshift/lpf15o: J2.24, P20.3
/lvlshift/lpf20o: J2.11, P20.5
/lvlshift/lpf40o: J2.23, P20.7
/lvlshift/lpf80o: J2.10, P20.9
/lvlshift/lpf160o: J2.22, P20.11
/lvlshift/lpf_0_12v: C12.1, P21.1, U2.15
/lvlshift/lpf_1_12V: C13.1, P21.3, U3.15
/lvlshift/lpf_2_12v: C14.1, P21.5, U2.4
/lvlshift/lpf_3_12v: C15.1, P21.7, U3.4
/lvlshift/lpf_4_12v: C19.1, P21.9, U2.2
/lvlshift/lpf_5_12v: C20.1, P21.11, U3.2
/lvlshift/lpf_10: J1.11, P20.2, P21.2
/lvlshift/lpf_15: J1.6, P20.4, P21.4
/lvlshift/lpf_20: J1.3, P20.6, P21.6
/lvlshift/lpf_40: J1.1, P20.8, P21.8
/lvlshift/lpf_80: J1.2, P20.10, P21.10
/lvlshift/lpf_160: J1.4, P20.12, P21.12
/lvlshift/swr_fd: J1.14, P20.14, P21.14
/lvlshift/swr_rv: J1.15, P20.16, P21.16
/lvlshift/swrf: J2.16, P20.13
/lvlshift/swrr: J2.15, P20.15
/mini_amp/AMP12V: C37.1, C38.1, L5.1, R18.1, U7.8
/ps/+13.8VA: C40.1, F1.1, U11.2, U12.2
/ps/+13.8VB: C43.1, C46.1, F1.2, R23.2, R24.2, U10.1, U10.4
/ps/+13.8VRA: C41.1, C44.1, R23.1, U8.1, U8.4
/ps/+13.8VRB: C42.1, C45.1, R24.1, U9.1, U9.4
/ps/RP_5V: C48.1, C51.1, C54.1, P2.1, U9.2
/rp_conn/SWR_R: P16.3, P17.3, P18.3, P19.3
/tr_switch/12V_Relay: C32.1, C33.1, K1.1, K2.1, L3.1
GND: C1.2, C2.2, C3.2, C4.2, C5.2, C6.2, C7.2, C8.2, C9.2, C10.2, C11.2, C12.2, C13.2, C14.2, C15.2, C16.2, C17.2, C18.2, C19.2, C20.2, C21.2, C22.2, C23.2, C24.2, C25.2, C26.2, C27.2, C28.2, C29.2, C31.2, C32.2, C33.2, C35.2, C37.2, C38.2, C40.2, C41.2, C42.2, C43.2, C44.2, C45.2, C46.2, C47.2, C48.2, C49.2, C50.2, C51.2, C52.2, C53.2, C54.2, C55.2, C56.2, CON1.2, CON1.3, J1.7, J1.8, J1.9, J3.2, J3.3, J3.4, J3.5, J4.2, J4.3, J4.4, J4.5, J5.2, J5.3, J5.4, J5.5, J8.2, J8.3, J9.2, J9.3, J10.2, J10.3, J11.2, J11.3, P1.25, P1.26, P2.21, P2.22, P2.25, P2.26, P5.2, P8.2, P9.2, P10.2, P11.2, P14.2, P15.2, R14.2, R17.2, SW1.2, T1.3, T2.4, U1.10, U1.17, U1.49, U1.57, U2.8, U3.8, U4.8, U5.5, U5.6, U5.7, U5.8, U5.9, U6.2, U6.4, U7.4, U8.3, U9.3, U10.3, U11.1, U12.1
unnamed: C16.1, J2.4, U2.10
unnamed: C17.1, J2.1, U3.10
unnamed: C18.1, J2.2, U2.12
unnamed: C21.1, J2.14, U5.16
unnamed: C22.1, P7.1, U5.15
unnamed: C23.1, J2.3, U3.12
unnamed: C30.2, J10.1
unnamed: C31.1, C56.1, L7.1, R25.1, R26.1, R27.1
unnamed: C34.1, P14.1
unnamed: C34.2, U6.3
unnamed: C36.1, L4.2, U6.1
unnamed: C36.2, J4.1, R14.1
unnamed: C39.1, P15.1
unnamed: C39.2, T2.6
unnamed: J1.10, P7.2, P7.4
unnamed: J3.1, P13.2
unnamed: J5.1, T1.1
unnamed: K1.2, K1.7, K2.2, K2.7
unnamed: K1.3, K1.6, P8.1
unnamed: K1.4, K1.5, P9.1
unnamed: K2.3, K2.6, P10.1
unnamed: K2.4, K2.5, P12.1, P13.1
unnamed: L4.1, R13.2
unnamed: LED_A1.2, R1.1
unnamed: LED_B1.2, R3.1
unnamed: LED_C1.2, R2.1
unnamed: LED_D1.2, R4.1
unnamed: P3.2, U1.52
unnamed: P3.4, U1.51
unnamed: P4.2, R11.1, U1.28
unnamed: P4.4, R6.1, U1.27
unnamed: P7.3, U3.6, U5.2, U5.3, U5.4
unnamed: P11.1, P12.2
unnamed: P2.13, P16.2, P16.4, P16.6
unnamed: P2.15, P17.2, P17.4, P17.6
unnamed: P2.16, P18.2, P18.4, P18.6
unnamed: P2.14, P19.2, P19.4, P19.6
unnamed: P5.1, P22.1
unnamed: R7.1, U1.38
unnamed: R9.1, U1.21
unnamed: R10.1, U1.20
unnamed: R12.1, U1.37
unnamed: R15.1, R19.2, U7.2
unnamed: R15.2, T1.6
unnamed: R16.1, R20.2, U7.6
unnamed: R16.2, T1.4
unnamed: R17.1, R18.2, U7.3, U7.5
unnamed: R19.1, R21.1, U7.1
unnamed: R20.1, R22.2, U7.7
unnamed: R21.2, T2.1
unnamed: R22.1, T2.3
unnamed: U2.6, U5.1
VCC: C3.1, C4.1, L1.2, L2.2, L7.2, P1.1, P1.2, P22.2, R1.2, R2.2, R3.2, R4.2, U1.26, U2.1, U2.13, U3.1, U3.13, U4.1, U4.13

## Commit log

2017-12-02 Add Power Add On Jpg
2017-12-02 Upload Mezzanine Power Jpg

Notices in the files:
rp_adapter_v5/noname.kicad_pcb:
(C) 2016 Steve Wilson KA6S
